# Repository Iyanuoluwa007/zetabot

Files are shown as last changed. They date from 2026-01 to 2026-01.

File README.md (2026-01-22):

<p align="center">
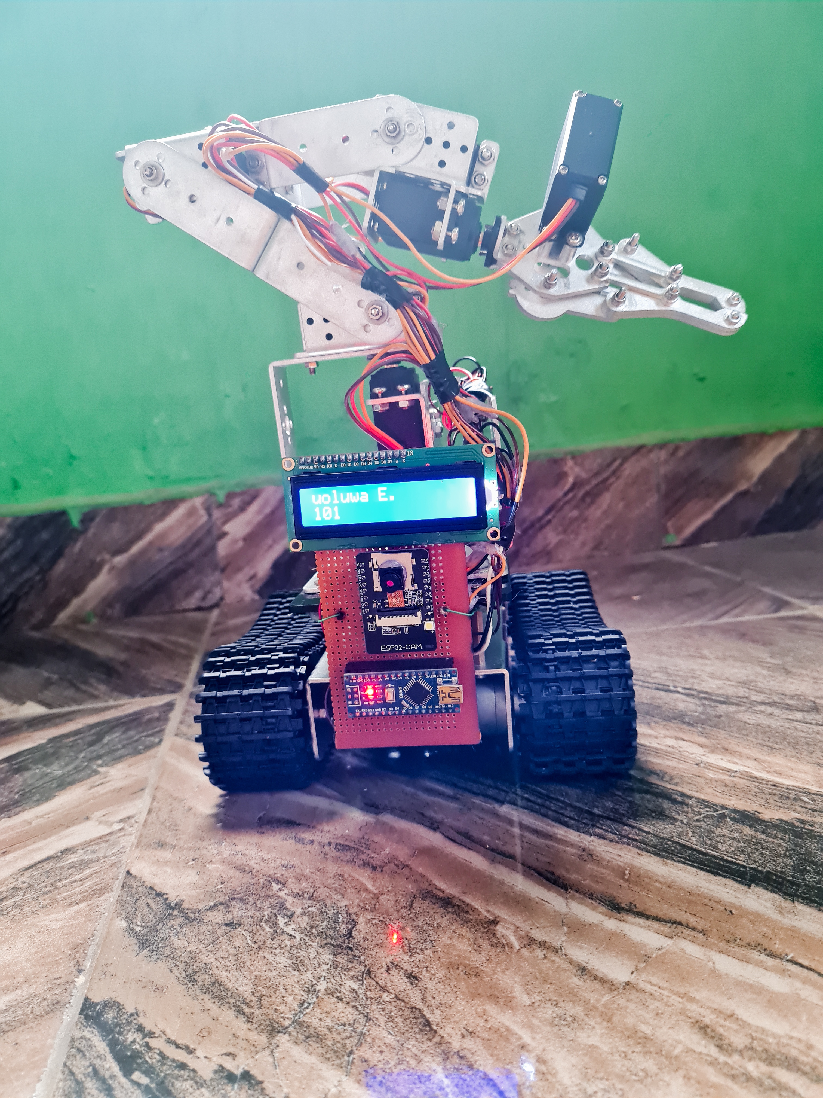
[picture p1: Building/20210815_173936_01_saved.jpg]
ZetaBot Robot
  
</p>

# 🤖 ZetaBot  
### Mobile Control Robotic Arm on Robotic Tank Wheel

> A low-cost, mobile robotic platform combining a robotic arm and tank-wheel locomotion, controlled via a custom Android app with live video streaming.

---

## 📌 Project Overview

**ZetaBot** is a research focused mobile robot designed for field applications such as agriculture, inspection, and robotics experimentation.  
It integrates a **robotic arm**, **tank wheel mobility**, **Bluetooth control**, and **Wi-Fi video streaming** using affordable, open-source hardware.

The system is controlled through a **custom Android application** built with Kodular, enabling real-time motion control and manipulation.

---

## 🧠 Key Features

✅ Mobile tank-wheel navigation  
✅ 6 - DOF robotic arm control  
✅ Android app control (Bluetooth)  
✅ Live video streaming over Wi-Fi  
✅ Low-cost, modular, and scalable design  
✅ LCD status feedback  
✅ Open-source software stack  

---

## ⚙️ System Architecture
**Control Flow:**

<p align="center">
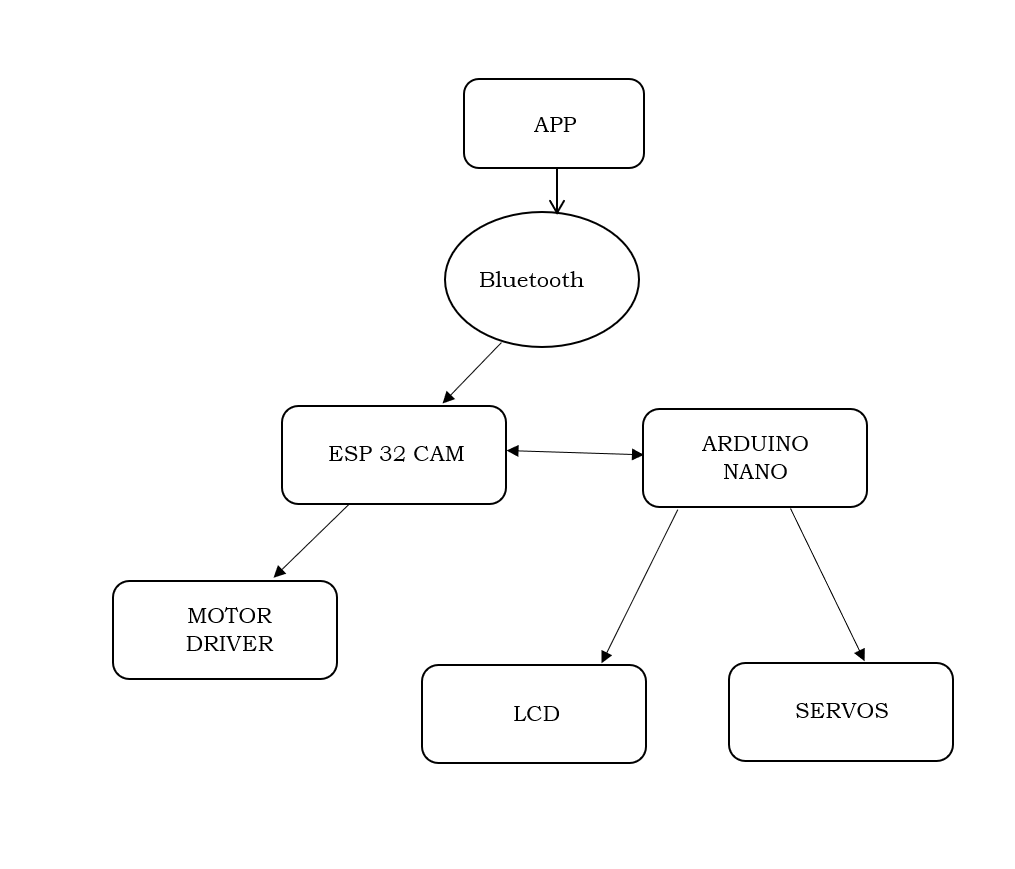
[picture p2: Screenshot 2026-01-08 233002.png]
ZetaBot System Architecture
  
</p>

- Android App → Bluetooth → ESP32-CAM  
- ESP32-CAM → Motor Driver (movement)  
- ESP32-CAM → Arduino Nano (arm & LCD)  
- ESP32-CAM → Wi-Fi → Live video stream  

---

## 🧩 Hardware Components

- ESP32-CAM (Wi-Fi + Bluetooth + camera)
- Arduino Nano
- L298N Motor Driver
- MG996R / MG995 Servo Motors
- 12V DC Geared Motors (Tank Wheels)
- 16×2 I2C LCD Display
- 18650 Lithium Batteries (3S & 2S)
- XL6019 DC - DC Boost Converter
- Solar Panel (5.5V, optional)
- Android Smartphone (Controller)

---

## 💻 Software & Tools

- **Arduino IDE** – Firmware development  
- **Kodular** – Android app builder  
- **ESP32 Camera Web Server** – Live video streaming  
- **C / C++** – Embedded programming  

---

## 📱 Mobile Application

The Android app is divided into two sections:

🔹 **Tank Control**
- Forward / Backward
- Left / Right
- Stop
- Headlight control

🔹 **Robotic Arm Control**
- Waist rotation  
- Shoulder movement  
- Elbow control  
- Grip open/close  
- Roll & pitch control  

---

## 🎥 Live Video Streaming

- ESP32-CAM streams live footage over Wi-Fi  
- Accessed via browser using ESP32 IP address  
- Useful for remote inspection and monitoring  

---

## 🧪 Results

✔ Stable movement and arm manipulation  
✔ Reliable Bluetooth communication  
✔ Clear live video stream over local Wi-Fi  
✔ Successful integration of all subsystems  

---

## 🚀 Applications

- Agricultural field research  
- Robotics education & prototyping  
- Remote inspection  
- Mechatronics research platform  
- Smart surveillance experiments  

---

## ⚠️ Limitations

- Bluetooth range limited compared to full internet control  
- Requires stable Wi-Fi for video streaming  
- Arm payload limited by servo torque  

---

## 🔮 Future Improvements

- Full internet based control (IoT)
- Autonomous navigation (SLAM)
- Object detection using computer vision
- Stronger servos & metal arm structure
- Cloud based monitoring dashboard

---

## 🎓 Academic Context

**Project Title:**  
*Design and Construction of a Mobile Control Robot Arm on a Robotic Wheel*

**Degree:**  
Bachelor of Engineering (B.Eng.) – Electrical & Information Engineering  

**Institution:**  
Landmark University, Nigeria  

**Year:**  
2022  

---

## 👤 Author

**Iyanuoluwa Enoch Oke**  
Robotics & AI Engineer  
📧 Email: [oke.iyanuoluwa12@gmail.com](mailto:oke.iyanuoluwa12@gmail.com)
🔗 LinkedIn: [Iyanuoluwa Enoch Oke](https://www.linkedin.com/in/iyanuoluwa-enoch-oke/)

---

## 📖 Citation & DOI

If you use this project in your research or work, please cite:

Oke, I. E. (2026). *ZetaBot: Mobile robotic platform with live video streaming and 6-DOF arm* (Version 1.0.1) [Software]. Zenodo.  
https://doi.org/10.5281/zenodo.18341042



---

⭐ *If you like this project, consider giving it a star!*  

---

## 🖼️ Project Gallery

<p align="center">
  
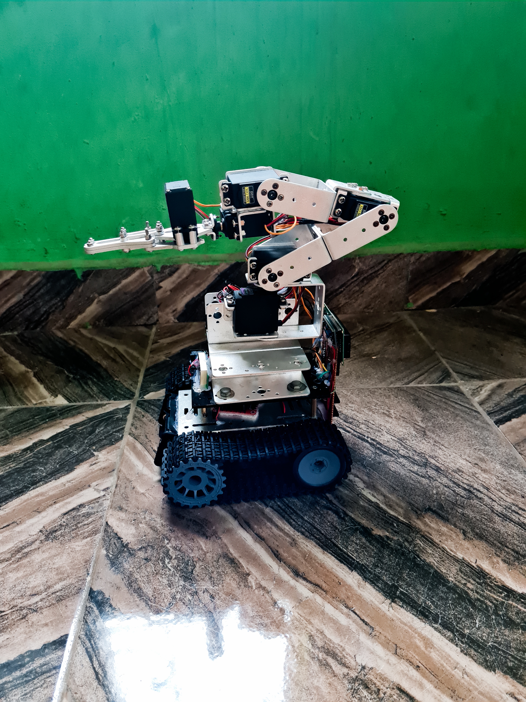
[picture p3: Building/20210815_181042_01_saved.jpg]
  
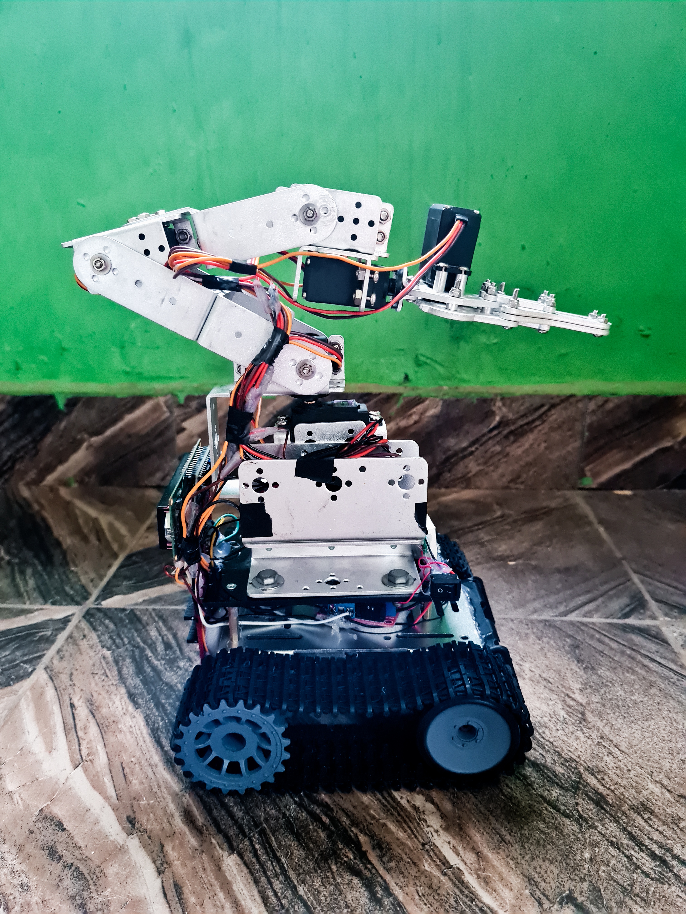
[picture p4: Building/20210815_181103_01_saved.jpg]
  
</p>

<p align="center">
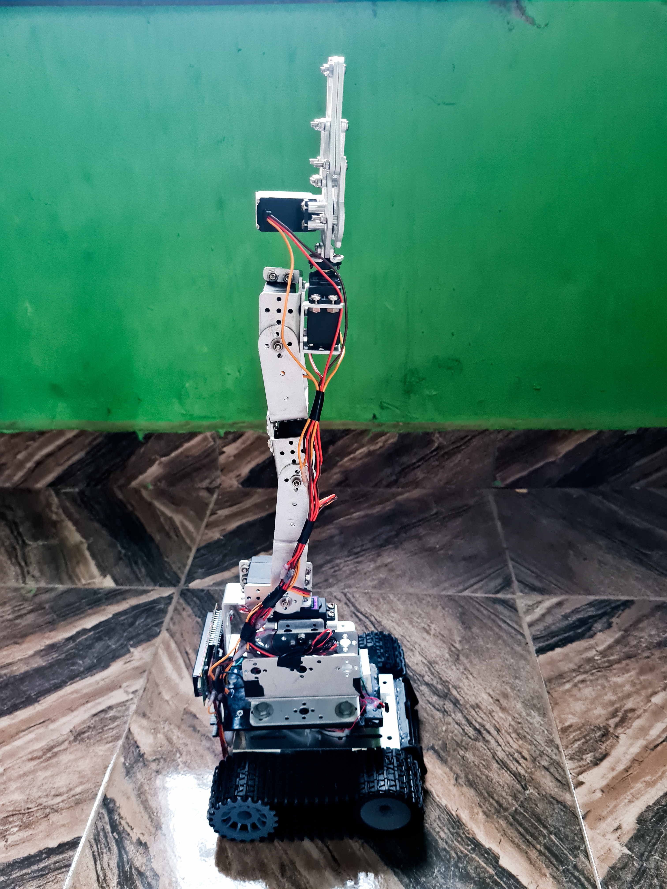
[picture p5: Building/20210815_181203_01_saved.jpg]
  
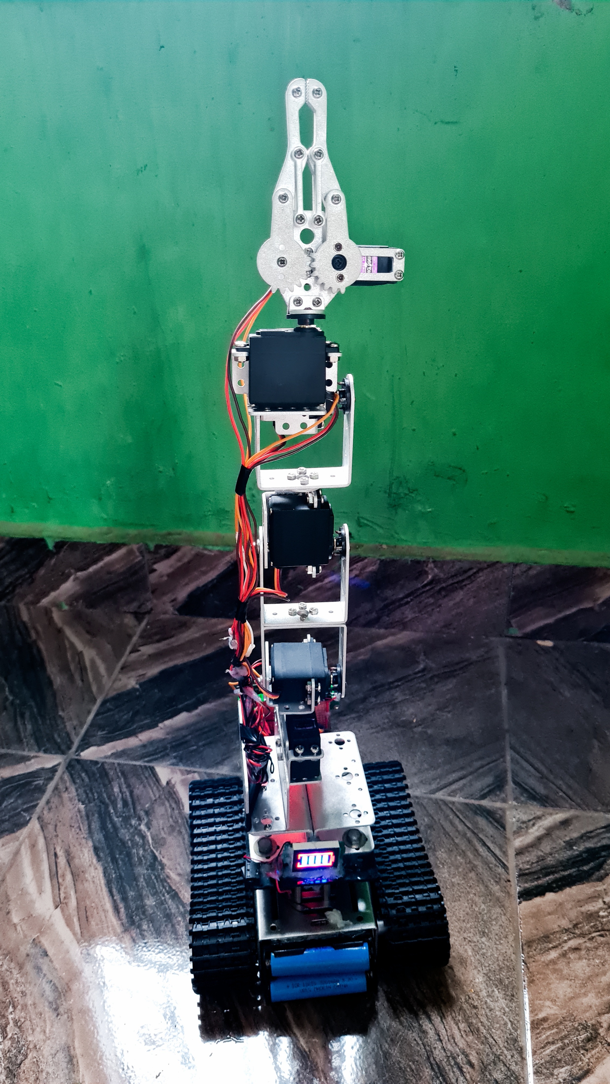
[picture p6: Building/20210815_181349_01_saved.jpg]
  
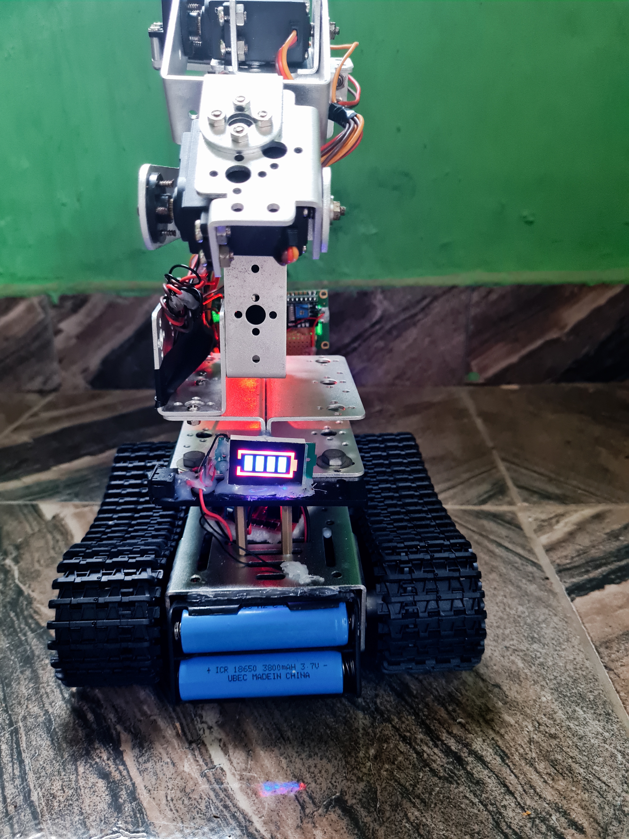
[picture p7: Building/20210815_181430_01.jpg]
  
</p>

### The app interface:
<p align="center">
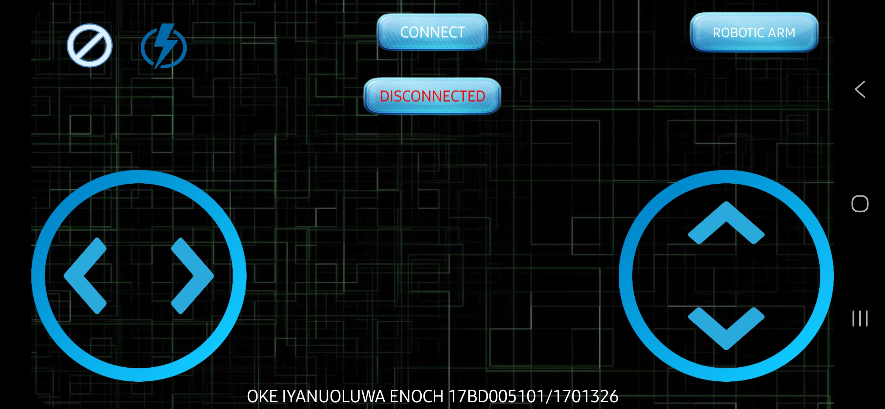
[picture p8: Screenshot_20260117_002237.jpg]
  
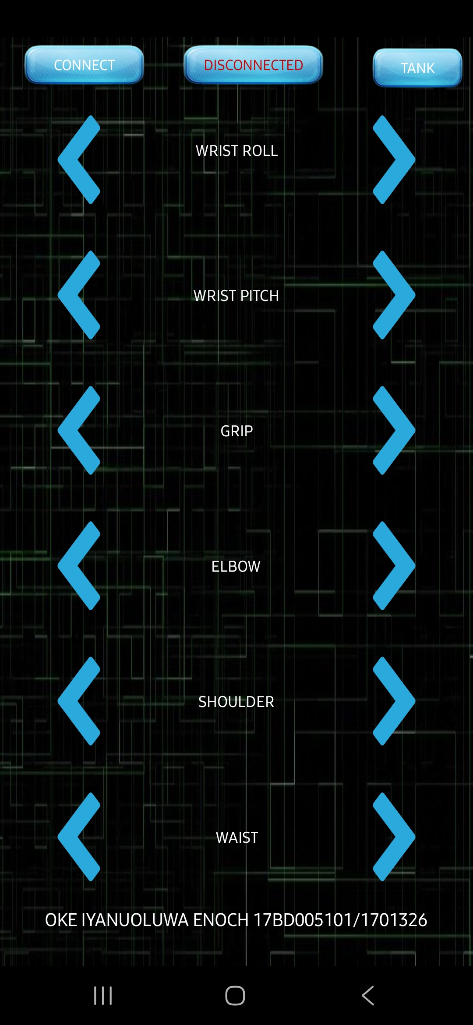
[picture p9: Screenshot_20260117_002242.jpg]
  
</p>

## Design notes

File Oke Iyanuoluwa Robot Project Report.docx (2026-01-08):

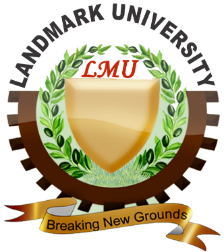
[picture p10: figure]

DESIGN AND CONSTRUCTION OF A MOBILE CONTROL ROBOT ARM ON A ROBOTIC WHEEL

BY

OKE IYANUOLUWA ENOCH

17BD005101/1701326

A PROJECT REPORT SUBMITTED TO

THE DEPARTMENT OF ELECTRICAL AND INFORMATION ENGINEERING

COLLEGE OF ENGINEERING

LANDMARK UNIVERSITY, OMU-ARAN, KWARA STATE, NIGERIA

IN PARTIAL FULFILLMENT OF THE REQUIREMENTS FOR THE AWARD OF BACHELOR OF ENGINEERING (B.ENG.) DEGREE IN ELECTRICAL AND INFORMATION ENGINEERING.

JULY 2022.

CERTIFICATION

The undersigned certifies that this project report, Titled ROBOTIC ARM ON ROBOTIC TANK WHEEL (ZETABOT) USING ESP 32 AND ARDUINO NANO was carried out by OKE IYANUOLUWA ENOCH, with Matriculation number 17BD005101 and meets the requirement of the Department of Electrical and Information Engineering (B.Eng.) degree in Electrical and Information Engineering.

__________________________ ___________________________

DR. P.K OLULOPE Date

(Supervisor)

_____________________________ _____________________________

DR. P.K OLULOPE Date

(Ag. Head of Department)

______________________________ _____________________________

(External Examiner) Date

DEDICATION

I dedicate this project work to the Almighty God, the source of my help and inspiration during this project, who has always been on my side throughout my academic journey at Landmark University. To my supervisor, Dr. P. K. Olulope without whose never-failing attitude to work, encouraging and scrutiny, this project would not have been as it is. I also dedicate this project to my family, the family of Mr Oke Babatunde who has been my source of everything throughout my academic career and also to my friends, and lecturers who were there for me and made an impact throughout this facet of my academic life.

ACKNOWLEDGEMENT

I would love to acknowledge the management of Landmark University for providing a conducive environment for learning and to carry out this project successfully.

I would also like to express my special thanks of gratitude to my supervisor Dr. P. K Olulope who gave me the golden opportunity to do this wonderful project on the Topic Robotic Arm on Robotic Tank Wheel Using Esp 32 And Arduino Nano, which also helped me in doing a lot of research and I came to know about so many new things. I am grateful.

Secondly, I would also like to thank my parents and friends, who helped me a lot in finalizing this project within the limited time frame.

SECTION | CONTENTS | PAGE
ii | CERTIFICATION | ii
iii | DEDICATION | iiI
iv | ACKNOWLEDGEMENT | iv
v | TABLE OF CONTENTS | v – vi
vii | TABLE OF FIGURES | vii
1 | CHAPTER 1: INTRODUCTION
1.1 | INTRODUCTION | 1
1.2 | BACKGROUND OF STUDY | 1
1.3 | AIM AND OBJECTIVES | 2
1.4 | SCOPE AND LIMITATIONS OF THE PROJECT | 2
1.5 | STATEMENT OF THE PROBLEM | 3
2 | CHAPTER 2: LITERATURE REVIEW
2.1 | HISTORY OF ROBOTICS | 4
2.2 | THE FIRST MODERN ROBOTS | 4
2.3 | MICROCONTROLLER | 5
2.3.1 | TERMINOLOGY | 5
2.3.2 | ESP 32 | 5
2.3.3 | ARDUINO NANO | 8
2.3.4 | POWER SUPPLY | 9
2.3.5 | SERIAL COMMUNICATION | 9
2.4 | MOTOR DRIVER | 9
2.5 | MOTOR | 12
2.6 | SERVO | 13
2.7 | 16 * 2 LCD SCREEN | 14
2.8 | ARDUINO IDE | 15
2.9 | KODULAR | 16
2.11 | 18650 15A 3S CHARGER MODULE | 17
2.12 | XL6019 DC TO DC BOOSTER MODULE | 17
2.13 | 5.5v 70ma SOLAR PANEL | 18
3 | CHAPTER 3: DESIGN AND METHODOLOGY
3.1 | RESEARCH METHODOLOGY | 19
3.2 | TOOLS | 20
3.2.1 | HARDWARE | 20
3.2.2 | SOFTWARE | 20
3.3 | SYSTEM DESIGN | 21
3.4 | CIRCUIT DESIGN | 22
3.5 | METHODOLOGY | 23
3.5.1 | SETTING UP THE ESP 32 CAM AND ARDUINO NANO ON ARDUINO IDE | 23
3.5.2 | BUILDING THE APP ON KODULAR | 23
3.5.4 | CONNECTING I2C LCD TO THE ARDUINO NANO | 24
3.5.5 | CONNECTING SERVO TO THE ARDUINO NANO | 24
3.5.6 | CONNECTING THE MOTOR CONNECTED TO MOTOR DRIVER TO ESP 32 CAM | 25
3.5.7 | PROGRAM CODE | 26
4 | CHAPTER 4
4.1 | RESULTS AND DISCUSSION | 43
5 | CHAPTER 5
5.1 | RECOMMENDATION | 44
5.2 | CONCLUSION | 44
| REFERENCES | 45

Fig 2.3.2 | LAYOUT OF ESP 32 CAM | 8
Fig 2.3.3 | LAYOUT OF ARDUINO NANO | 8
Fig 2.4.1 | SCHEMATIC DIAGRAM FOR MOTOR DRIVE MODULE | 11
Fig 2.4.2 | LAYOUT OF L298N MODULE | 11
Fig 2.5 | DIAGRAM OF 12V330 GEARED MOTOR | 13
Fig 2.6.1 | SCHEMATIC DIAGRAM FOR MG996R SERVO MOTOR | 13
Fig 2.6.2 | LAYOUT OF MG996R SERVO MOTOR | 14
Fig 2.7 | LAYOUT OF 16 X 2 LCD | 14
Fig 2.8 | ARDUINO IDE | 15
Fig 2.9 | LAYOUT OF KODULAR | 16
Fig 2.10 | LAYOUT OF 18650 15A 3S CHARGER MODULE | 17
Fig 2.11 | LAYOUT OF XL6019 DC TO DC BOOSTER MODULE | 18
Fig 2.12 | LAYOUT OF 5.5V 70MA SOLAR PANEL | 18
Fig 3.1 | FLOW CHART OF RESEARCH METHODS | 19
Fig 3.3.1 | BLOCK DIAGRAM | 21
Fig 3.3.2 | PICTORIAL CIRCUIT DIAGRAM | 22
Fig 3.4 | CIRCUIT DIAGRAM | 22
Fig 3.5.4 | CONNECTING THE I2C LCD TO THE ARDUINO NANO | 24
Fig 3.5.5 | CONNECTING SERVO TO THE ARDUINO NANO | 25
Fig 3.5.6 | PICTORIAL CIRCUIT DIAGRAM OF CONNECTING THE MOTOR CONNECTED TO MOTOR DRIVER TO ESP 32 CAM | 26
Fig 4.1 | FINAL CONSTRUCTED PROJECT RESULT | 43

TABLE OF FIGURES

CHAPTER 1

1.1 INTRODUCTION

It is true that in recent years, the power, functionality, and ubiquity of computers and the Internet have outpaced earlier projections for the rate of technological innovation and utility in everyday life. Experts anticipate that the world will soon be flooded with sophisticated computer chips, which will progressively find their way into our products, houses, clothes, and even our bodies.

A nearly similar goal, on the other hand, has remained elusive. Unlike the widely unanticipated main streaming of computers, the robotics team failed to live up to the 1950s predictions. Experts were astounded by the possibilities at this point. The computer's seemingly magical computation believes that precisely the proper software is written down. Computers have the potential to become the artificial brains of advanced autonomous robots. They believe that such robots will mop floors, mow lawns, and generally eradicate chores from our life in a decade or two.

That did not appear to be the case. Industrial robots have had a significant impact on the automobile sector, as well as other industries. However, this level of automation falls far short of what many scientists and engineers had hoped for in terms of versatility, portability, and automation. Thousands of researchers have become frustrated in their pursuit of these robots, and hundreds of firms have gone bankrupt. It's not that the mechanical "body" is unreachable; industrial robots demonstrate that articulated arms and other mobile systems appropriate for manual tasks already exist. Instead, the computerized pairing brain has not yet advanced to the level of sophistication required to construct a human-like robot.

1.2 BACKGROUND OF STUDY

In a variety of fields, robots are gaining traction. Almost every day, we read in the press about robots in nursing homes giving the old company or cars that can park or even drive themselves without human supervision. It appears that the world is becoming increasingly automated when we call a corporation and are connected to a computer. And the robots are getting smarter; scientists are working on making more friendly robots that can read facial expressions and have conversations.

The progression appears to go from limited industrial robots to increasingly autonomous machines and systems, with singularity machines outsmarting humans in science fiction films like Terminator or I-Robot at the extreme, more speculative end of the spectrum.

In this thesis, the word "autonomous system" is used to refer to several phrases such as "robot," "artificial agent," and "unmanned aerial vehicle." The autonomy, not necessarily the embodiment commonly associated with robots, is the relevant feature for the philosophical concerns in the thesis. It's just as important to have an autonomous system integrated in something that isn't a robot. However, as it is in the literature, the term robot is most usually used.

Although roboticists do not appear to agree on how to interpret the term robot, autonomy or independence appears to be a common denominator. A computer attached to a printer, for example, would be a robot if it were defined as "a computer with sensors and actuators that allow it to interact with the external world." Something more, some amount of "thinking" or "doing," is required to distinguish it from automata such as thermostats or computers attached to printers.

1.3 AIM AND OBJECTIVES

1.3.1 AIM:

To develop a low-cost research robot used in any area of field.

1.3.2 OBJECTIVES:

Objective of this project are as follows:

i. To design an inexpensive system that is user-friendly and easy to use.
ii. To construct a mobile app control robot for research purpose.
iii. To develop an internet base control system that enables transfer and receiving data through the internet.
iv. To interface the system with an internet android application enabling cloud data communication.

1.4 SCOPE AND LIMITATIONS OF THE PROJECT

The project scope, which is in line with its aim to use an affordable agrotechnology robot, targets for field research that is controlled via a mobile app. Esp 32 Cam and Arduino Nano are the main microcontrollers used for the system as communication to a cloud store through the internet between the cloud store and the mobile app.

The project will not be limited to just field research purposes only. A Kodular Mobile Application, Bluetooth serves as the intermediate between the user sending instructions through Bluetooth connection.

1.5 STATEMENT OF THE PROBLEM

Despite robot researchers' efforts and research, the goal of emulating human intelligence and appearance has yet to be reached. The majority of robots are not adaptable, and they do not recognize objects effectively. Prioritizing the inefficiencies connected with robotics technology is critical for its successful and proper operation. Though widespread usage of robotics technology will eliminate many human jobs, it will result in increased unemployment in the society. Because the use of robots to do diverse tasks will result in the loss of human jobs, the implementation should be done systematically. Robotic advancements will reduce the number of high-end precision tasks and will benefit a variety of industries, including agriculture, military, and health care. As a result, robots will be used as workplace assistants with a degree of balance between genuine requirements and greed. Many jobs that are beyond human capability can be accomplished with the aid of robotics, which will be quite beneficial in its functioning. The growth of robot technology will be incredible, and robots can now be found in almost every field, from transportation to health, recreation to industry.

CHAPTER 2

LITERATURE REVIEW

2.1 History of Robots

One of the first examples of a mechanical device designed to do a particular physical task on a regular basis may be found in Egyptian water clocks from around 3000 B.C. These clocks used human figures to strike the hour bells. The pulley and screw were constructed by Archytus of Taremtum, who also invented a flying wooden pigeon in 400 B.C. Hydraulically powered statues that could speak, gesture, and prophesy were common in Hellenistic Egypt during the second century B.C.

A doll that resembles a human was made in the first century AD by Petronius Arbiter. Giovanni Torriani created a wooden robot that could deliver the Emperor's daily bread in 1557. Before the twentieth century, the number of inventive but unusable automata (i.e., robots) reached its height in the 1700s. The nineteenth century saw the development of numerous new robotic creations, such as Thomas Edison's talking doll and a steam-powered robot created by Canadians. The modern robot was made possible by scientific developments in the field of robotics made in the 20th century, despite the fact that previous historical advances may have planted the seeds of inspiration for it. The modern robot may have been inspired by these historical findings, but scientific advancement in the field of robotics in the 20th century far exceeds earlier successes.

2.2 The First Modern Robots

Early in the 1950s, a man from Louisville, Kentucky named George C. Devol created the first robots as we know them today. The "Unimate," or "Universal Automation," reprogrammable manipulator was created by him, and it was granted a patent. For the following ten years, he made failed attempts to market his products in the sector. Businessman and engineer Joseph Engleberger purchased Devol's robot patent in the late 1960s and turned it into an industrial robot. He then founded Unimation to produce and sell the robots. Because of his contributions, Engleberger is known in the industry as "the Father of Robotics." New robot development has advanced significantly in academia as well. In 1958, Charles Rosen oversaw a research group at Stanford Research Institute that created "Shakey," a considerably more advanced robot than the Unimate that had been created initially for specialized industrial applications. Shakey was able to walk around the space, see the action through his television "eyes," travel across uncharted territory, and to some extent react to his environment. He was given the name because of his clumsy and clattering actions.

2.3 MICROCONTROLLER

2.3.1 TERMINOLOGY

A microcontroller is a single-chip microcomputer made with VLSI technology. Microcontrollers are frequently referred to as embedded controllers. Microcontrollers with varied word lengths, such as 4bit, 8bit, 64bit, and 128bit microcontrollers, are now available on the market. Microcontrollers are compact microcomputers used to control the functions of embedded systems in office equipment, robotics, home appliances, automobiles, and other devices. Memory, peripherals, and, most crucially, a CPU are all included in a microcontroller.

Microcontrollers are primarily used in gadgets that require the user to exercise some level of control.

2.3.2 ESP 32 CAM

This project also made use of Esp 32 Cam. With the ESP32-S chip, the ESP32-CAM is a very compact camera module. The camera on the module is an OV2640. Additional GPIOs are available for connecting devices. The controller is built on a 32-bit CPU that operates at a maximum frequency of 240MHz. It contains an external 4M PSRAM in addition to its internal 520 KB SRAM. It has a SoC module that combines 802.11b/g/n Wi-Fi and Bluetooth/BLE. It supports embedded Lwip, FreeRTOS, and image Wifi upload. There is a PSRAM Chip with an onboard voltage regulator IC. The board is breadboard friendly and contains a single reset button. On the board, there is an LED that can be utilized as a signal.

This module comes with an antenna built in, and if an extra antenna with more power and range is required, it may be connected to the IPEX connector. You must attach a jumper or a zero-ohm resistor on the PCB next to the antenna in order to utilize it.

ESP32-CAM Specifications

Since the ESP32-CAM is based on the ESP32-S module, it has similar features. It has these characteristics:

i. 802.11b/g/n Wi-Fi
ii. Bluetooth 4.2 with BLE
iii. UART, SPI, I2C and PWM interfaces
iv. Clock speed up to 160 MHz
v. Computing power up to 600 DMIPS
vi. 520 KB SRAM plus 4 MB PSRAM
vii. Supports Wifi Image Upload
viii. Multiple Sleep modes
ix. Firmware Over the Air (FOTA) upgrades are possible
x. 9 GPIO ports
xi. Built-in Flash LED

OV2460 Camera

The Camera Module is the most crucial component of the ESP32 CAM. The OV2640 Camera Module, which includes a 24 Pin Camera Holder, is the available Camera Module. It features a camera resolution that is the highest, at 1600 1200.

There is a connecting strip with gold plating. The camera and ESP32 are connected using this connector.

SD Card Support

An SD Card Holder that can accommodate cards up to 16GB is located on the back. When creating projects that rely on photographs, the SD card is utilized to store the images. Simply placing the SD Card into the SD Card Adapter establishes the connection.

Camera Specifications

On the back, there is an SD Card Holder that can hold cards up to 16GB. The SD card is used to store the images when developing projects that rely on photos. The connection is made simply by inserting the SD Card into the SD Card Adapter

i. 2 Megapixel sensor
ii. Array size UXGA 1622×1200
iii. Output formats include YUV422, YUV420, RGB565, RGB555 and 8-bit compressed data
iv. Image transfer rate of 15 to 60 fps

ESP32 CAM GPIO Pins

Numerous GPIO pins, including UART, SPI, I2C, PWM, ADC, and DAC, are supported. This module provides both a 5V pin and a 3.3V VCC pin. Additionally, there are several GND Pins.

The following pins are internally connected to the microSD card reader:
GPIO 14: CLK
GPIO 15: CMD
GPIO 2: Data 0
GPIO 4: Data 1 (also connected to the on-board LED)
GPIO 12: Data 2
GPIO 13: Data 3

ESP32-CAM FTDI Connection

For the purpose of programming the board, a USB-to-TTL Converter Module or an FTDI Module must be used; there are numerous FTDI Module options based on the CP2102 or CP2104 chip, among others.

Make the connection between the FTDI module and the ESP32 CAM module as shown below to get started with the module.

Connect the ESP32's 5V and GND pins to the FTDI module's 5V and GND pins. Rx and Tx should be similarly connected to UOT and UOR Pin. The IO0 and GND Pins must be connected via a short circuit, which is the most crucial step. In order to program the device, do this. After programming is complete, the IO0 and GND must be removed. The Esp 32 Cam can be programmed using the Arduino IDE software and is compatible with LUA, Java, C, and C++. The design of Esp 32 Cam is seen in the figure.

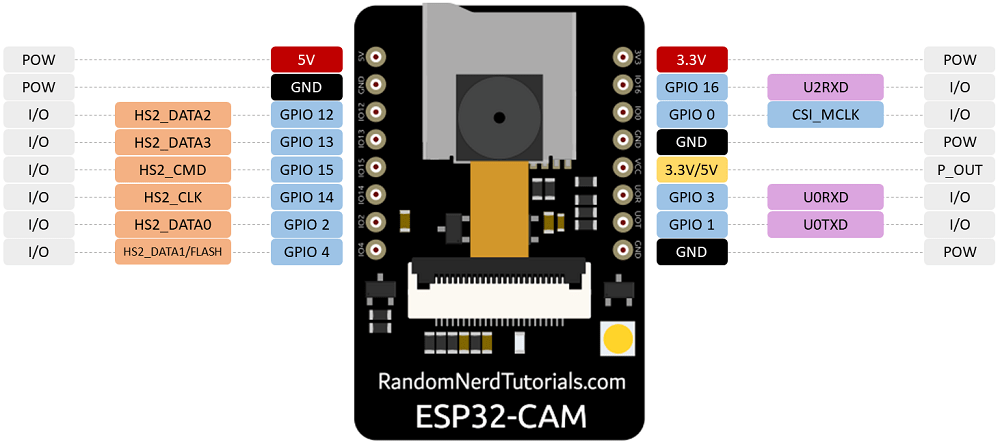
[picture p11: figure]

Fig 2.3.2: Layout of Esp 32 Cam

2.3.3 ARDUINO NANO

For this project, an Arduino Nano board was also utilized. It is an ATmega328-based, surface-mount embedded version of Arduino that is compact, complete, and compatible with breadboards. Electrically speaking, it is identical to the Arduino Diecimila save for having more analog input pins and a built-in +5V AREF jumper. The Nano 3.0 connects to a computer using a Mini-B USB cable and can be powered by a 5V regulated external power supply, a 6-20V unregulated external power supply, or the Mini-B USB connection (pin 30). (pin 27). The greatest voltage source is automatically chosen as the power supply. The Nano features more breadboard space for users thanks to its smaller size than either the Arduino Uno or Micro, which both have breadboard functionality. Additionally, it has a pin arrangement that complements the Mini or the Basic Stamp (TX, RX, ATN, GND on one side, power, and ground on the other).

The Arduino Nano may be programmed using the Arduino IDE software, and it supports the programming languages LUA, Java, C, and C++. The Arduino Nano's layout is seen in the figure.

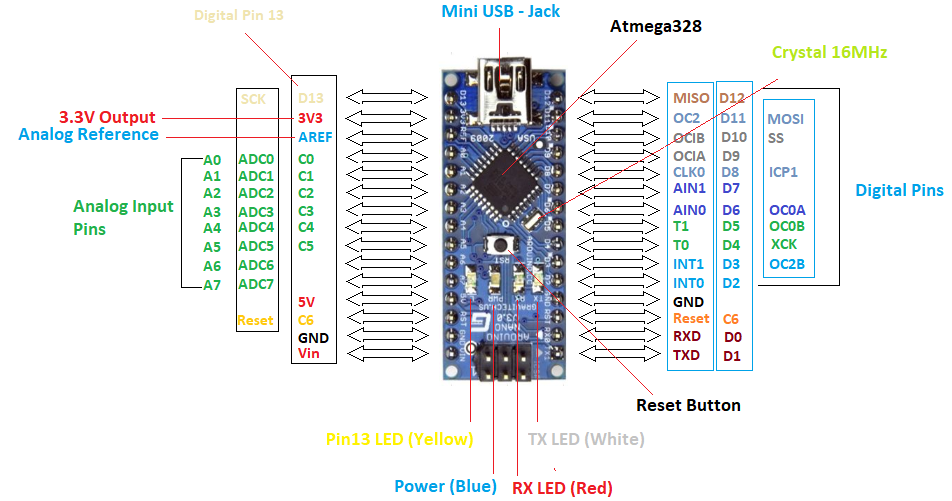
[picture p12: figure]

Fig 2.3.3: Layout of Arduino Nano

2.3.4 POWER SUPPLY

Esp 32 Cam Power Supply

The Esp 32 Cam can be power by two methods which are through the onboard VIN pin through which a regulated 5v voltage source is connected to and also through FTDI Module to a computer system. The Esp 32 cam can be activated with voltages ranging from 3.3v to 5v. The Esp 32 Cam has an AMS1117 voltage regulator that creates the required voltage for the Esp. The AMS1117 has an absolute maximum input voltage of 15V. It has a dropout voltage of 1.1v -1.3v. The onboard 5v and 3.3v pin can supply power to connected devices.

Arduino Nano Power Supply

The Arduino Nano can be power by two methods which is through the on-board Mini-B USB connector to a computer system and the onboard VIN pin through which a regulated 5v. The Arduino Nano has an LM1117IMPX-5.0 voltage regulator that supplies 5v to the Arduino Nano. The LM1117IMPX-5.0 has an absolute maximum input of 20v. The LM1117IMPX-5.0 supports input voltages between 7V and 12V with a maximum current of 900mA. The onboard 5v and 3.3v pin can supply power to connected devices.

2.3.5 SERIAL COMMUNICATION

Serial communication is used for communication between the Arduino boards and a computer or other devices. All Arduino boards have at least one serial port (also known as a UART or USART). It communicates on digital pins 0 (RX) and 1 (TX) as well as with the computer via USB.

2.4 MOTOR DRIVER

An integrated circuit chip called a motor driver IC is used to control motors in embedded and autonomous robotic systems. The L293D and ULN2003 are the most often utilized motor driver ICs in small robots and remote-controlled autos. Undoubtedly, a motor driver is something that makes a motor move in response to directions or inputs (high and low). It uses the low voltage provided by the controller or processor to drive a genuine motor, which needs a high input voltage. The motor driver IC controls the direction of the motor in accordance with the directives or instructions it gets from the controller.

The L298N Motor Driver Module

A monolithic circuit is built into the 15-lead Multiwatt and PowerSO20 packaging known as the L298N. It is a twin full-bridge high-voltage, high-current driver capable of driving inductive loads such as relays, solenoids, DC motors, and stepping motors. Two independent of input signal enable inputs can be used to enable or disable the device. An external sensing resistor can be connected to the corresponding external terminal once the bottom transistor emitters of each bridge have been connected together. An additional supply input is included to enable the logic to function at a lower voltage.

Specification

i. Driver: L298N
ii. Driver power supply: +5V~+46V
iii. Driver Io: 2A
iv. Logic power output Vcc: +5~+7V (internal supply +5V)
v. Logic current: 0~36mA
vi. Controlling level: Low -0.3V~1.5V, high: 2.3V~Vss
vii. Enable signal level: Low -0.3V~1.5V, high: 2.3V~Vss
viii. Max power: 25W (Temperature 75 Celsius)
ix. Working temperature: -25C~+130C
x. Dimension: 60mm*54mm
xi. Driver weight: ~48g
xii. Other extensions: current probe, controlling direction indicator, pull-up resistor switch, logic part power supply.

Hardware Diagram

i. CSA: The current test pin for motor A, this pin can be wired to a resistor for current testing or tied to a jumper to disable it.
ii. CSB: The current test pin for motor B, this pin can be wired to a resistor for current testing or tied to a jumper to disable it.
iii. VMS: VMS is the 5V-35V power source for the motor. VMS is positive, GND is negative.
iv. 5V: Power input for the logic circuit on the board.
v. 5V-EN: 5V source jumper. When the jumper is put on, The 78M05 supplies the 5V power for the logic circuit on the board from the VMS port (7V < VMS < 18V). The power of the logic circuit of the board is supplied by the 5V port when this jumper is put off.
vi. U1/2/3/4: Pull up resistor for IN1/2/3/4. Putting on the jumper enable the pull-up resistor for the microcontroller, putting off it disable it.
vii. EA/EB: EA/EB is to enable pin for the two motors A/B, the motor speed also can be controlled by the PWM of this pin.
viii. IN1/2/3/4: IN1/2/3/4 is the pin for the motor control. Motor B is the same as Motor A.

Its schematic diagram and Layout is as shown in figure (a) and (b):

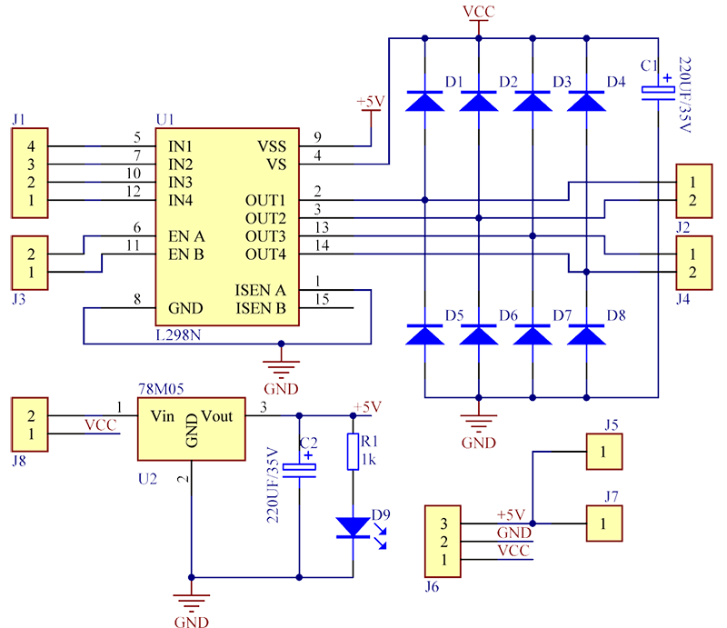
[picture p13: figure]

(a) Fig 2.4.1: Schematic diagram for motor drive module

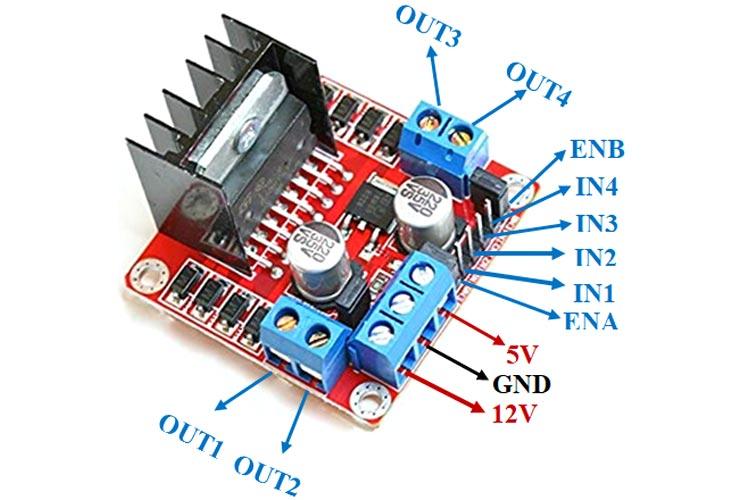
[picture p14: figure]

(b) Fig 2.4.2: Layout of L298N Module

2.5 MOTOR

A DC motor is any of a class of rotary electrical motors (https://en.wikipedia.org/wiki/Electrical_motor) that converts direct electrical current energy into mechanical energy. DC motor work on the current and voltage needed for the capabilities of microcontroller but DC moto is necessary to use some external device of electronic to drive the and control the motor, and it required individual power supply. There are many ways to drive the DC motor from the output of the device. However, transistors also use full to drive the DC motor and the other way to control the direction of the motor is L298N drive it is an integrated circuit.

How DC motor work

Stator, rotor, and armature are the three primary components of a DC motor. The revolving component known as the armature simple coil and a magnetic field are both present in the stator, which is permanently managed. Here, the armature is connected to the DC power source, and a two-piece ring that is attached within the motor shaft is known as the "commutator ring." A magnetic field was created by applying DC to the commutator, where flow travels through the coil.

Specification

i. Model: 112V330 to DC gear motor
ii. Rated Voltage: DC12V
iii. Original Speed: 1200rpm
iv. No-load Speed: 330rpm/0.24A
v. Maximum Efficiency Point: Load 4kg.cm/235rpm/2.5W/0.58A
vi. Maximum Power Point: Load 7kg.cm/215rpm/3.1W/0.65A
vii. Maximum locked rotor force: 13kg.cm
viii. Blocking Current: 4.8A
ix. Shaft Extension Size: 14.5mm
x. Motor Shaft Diameter: 4mm D3.5

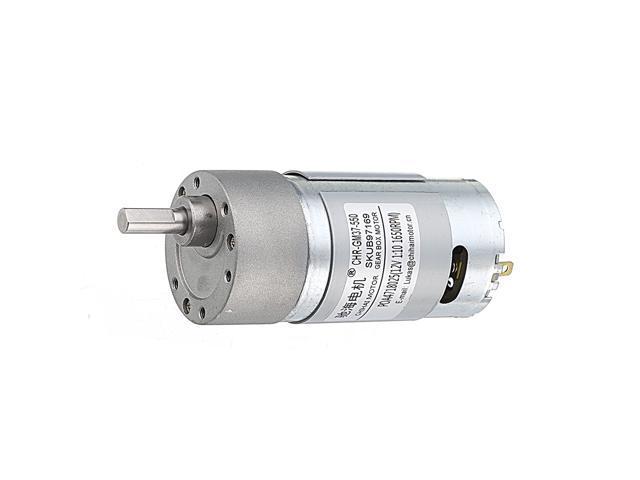
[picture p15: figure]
Engineering drawing Description generated with very high confidence

Fig 2.5: Diagram of 12v330 Geared Motor

2.6 SERVO

A servo motor is a rotary actuator or motor that enables exact angular position, acceleration, and velocity control. It possesses characteristics that a standard motor lacks. Standard servos are used to maintain a specific angle and use closed-loop feedback control. They are not intended for a full rotation. Servos are utilized in applications that require a lot of torque and precise rotation within a certain range of angles. The MG996R Servo Motor is a servo motor that uses PWM control signals to function. Based on the width of the pulse fed in by a signal input, the servo maintains a specific angle (position).

Specifications

i. Weight: 61 g
ii. Dimension: 54 x 38 x 20 mm approx.
iii. Gear Type: All Metal Gears
iv. Stall torque:12kg/cm(6V)
v. Power Supply: Through External Adapter
vi. Operation Voltage: 4.8 - 7.2 V
vii. Temperature range: 0'C to 55‘C
viii. Operating Speed: 0.17sec / 60 degrees (4.8V no load)
ix. Operating Speed: 0.13sec / 60 degrees (6.0V no load)
x. Pin configuration: Yellow / Light Orange / White (Signal), Red / Dark Orange (+5V), Brown/Black (Ground)

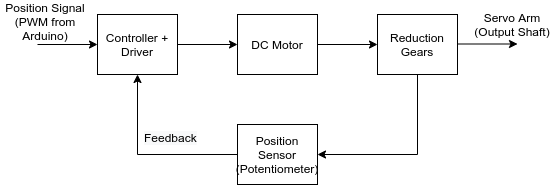
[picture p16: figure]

(a) Fig 2.6.1: Schematic diagram for MG996R Servo Motor

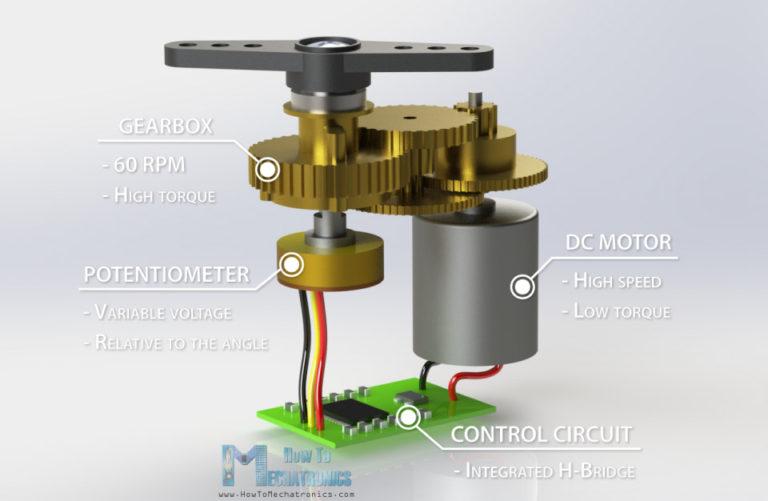
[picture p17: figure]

(b) Fig 2.6.2: Layout of MG996R Servo Motor

2.7 16 x 2 LCD SCREEN

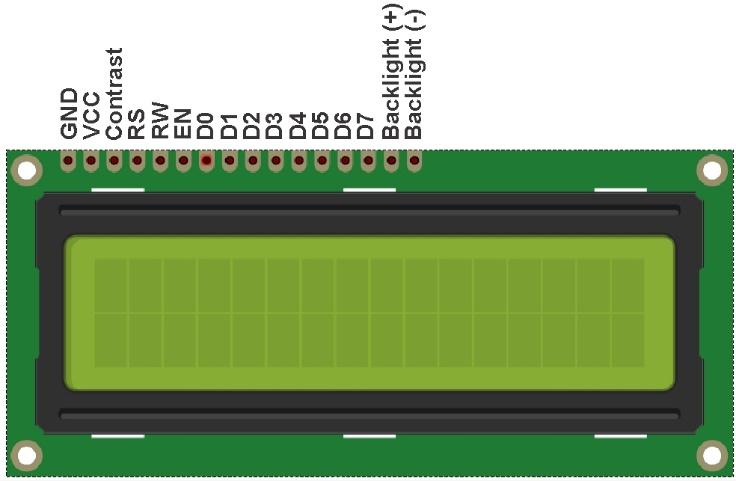
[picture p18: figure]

Liquid Crystal Display is an electronic module for displaying letters, numbers and characters. A 16 x 2 LCD means the screen can display 16 characters in two (2) lines. The LCD is used to display messages sent from Arduino Nano.

Fig 2.7: Layout of 16 x 2 LCD

2.8 ARDUINO IDE

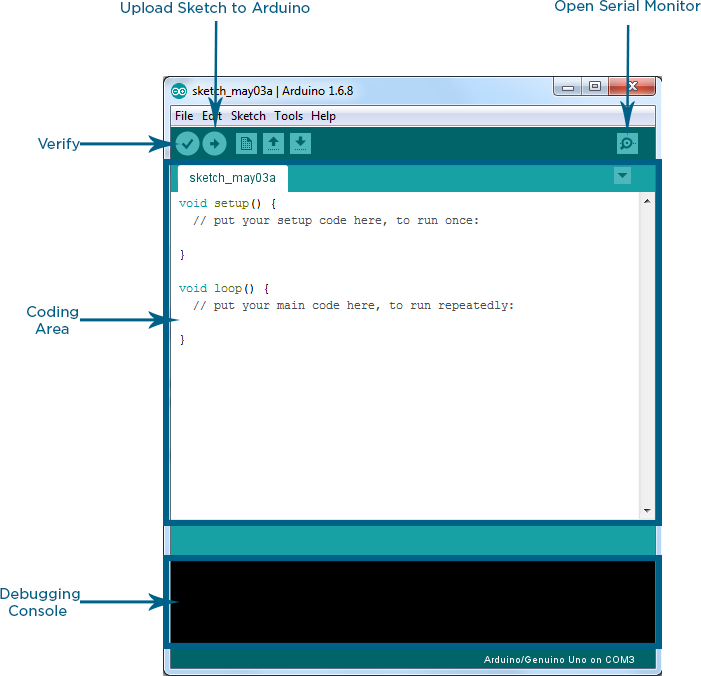
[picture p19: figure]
A picture containing graphical user interface Description generated with very high confidence

The Arduino IDE (Integrated Development Environment) is software that is used to write and upload codes to the Esp 32 Cam and Arduino Nano, after which it must have been installed on a computer system that may have a Linux, Windows or Mac OS X operating system. This software makes use of gcc, G++ compiler and accepts programs in C and C++. Appropriate settings must be done before coding on the software.

Fig 2.8: Arduino IDE

2.9 KODULAR

Kodular is an online suite that largely consists of an online web application that allows users to create apps without having to know how to code. Kodular Creator is an MIT App Inventor distribution, which means it's based on the App Inventor open source project, though it's a lot better. Kodular Creator, on the other hand, is not an open-source project, and the source code is hosted privately on GitHub, however, there are additional repositories related to the Suite. The most visible difference between this App Inventor package and the App Inventor open source project is that it has more components, more granular control over the app, and capabilities not found in the open-source version. The package also includes an online app store to compete with the Google Play Store, as well as an extensions IDE for advanced users to create additional Kodular Creator components. Kodular Account, a mechanism for controlling all of these services from a single location, is available to provide control over all of them.

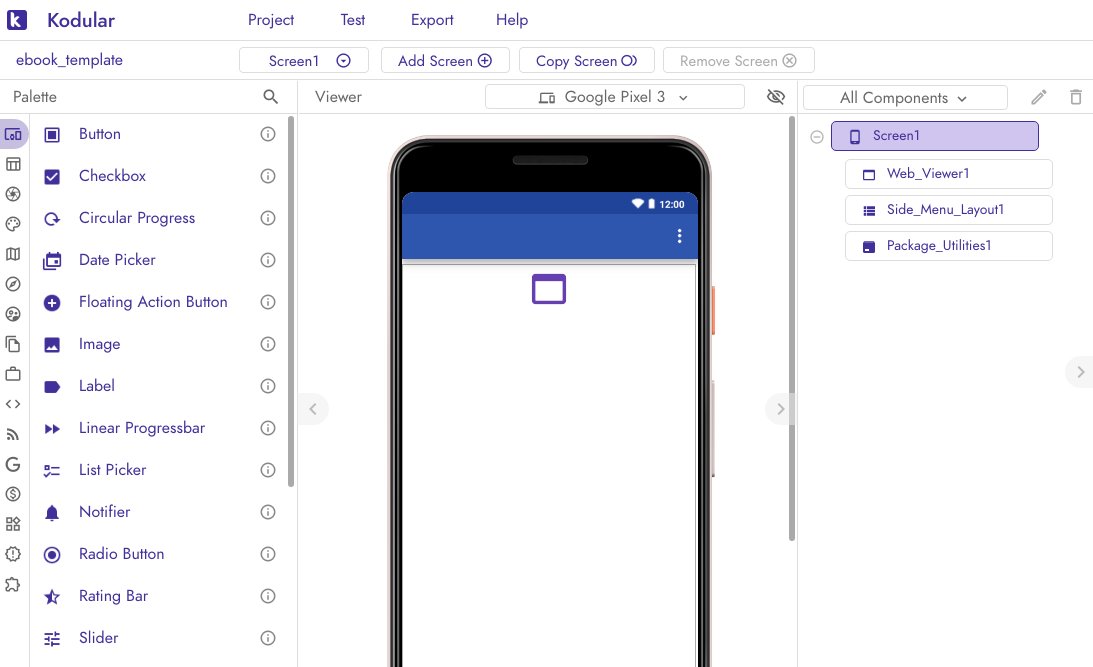
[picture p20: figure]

Fig 2.9 Layout of Kodular

2.10 18650 15A 3S CHARGER MODULE

This module is made for charging rechargeable lithium batteries using the constant-current/constant-voltage (CC/CV) charging method. In addition to safely charging a lithium battery the module also provides necessary protection required by lithium batteries.

The module specification

Model : HX-3S-FL25A-A

Charging voltage range: 12V

Over-discharge recovery voltage: 2.5v±0.05v,

Over-Discharge-Delay-Time: 144ms

Maximum Working Current: 10A

Maximum Peak current: 20A

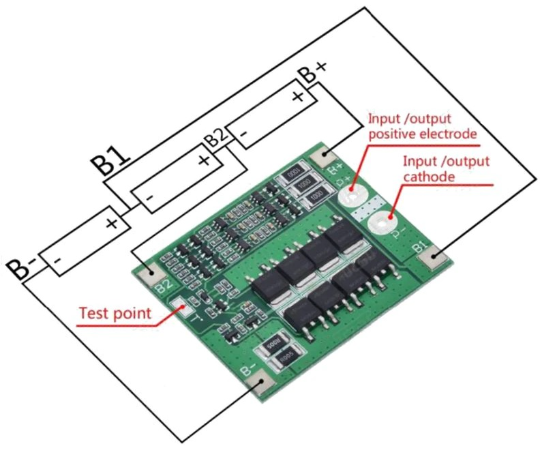
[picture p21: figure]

Fig 2.10: Layout Of 18650 15A 3s Charger Module

2.11 XL6019 DC TO DC BOOSTER MODULE

XL6019 DC-DC boost power supply module adjustable output regulator performance ultra LM2577 Model Specifications: XL6019 boost module Module Properties: non-isolated step-up Rectification: Non-Synchronous Rectification Input range: Limits: 3-40V, recommended values: 3V-35V Output Range: Limits: 5-45V, recommended values: 5V-40V (via rotary potentiometer) Input Current: Limits: 0-5A, recommended values: 0-3A Conversion efficiency: up to 94% Open frequency: 220KHz, the second generation of switching power supply technology Output ripple: less than 100mV Load regulation: &plusmn; 0.5% Voltage regulation: & plusmn; 0.5% Working temperature: Limits: -40 to +150 degrees Celsius, the recommended values: -20 to +85 degrees Celsius Reverse polarity protection: protection against reverse input 40V Size: 50MM 28MM 13MM With back protection, import TDK inductor, with a connecting column, the output 5V/12V/24V can be adjusted, performance beyond LM2577. Using conventional topology BOOST as a constant voltage output, the internal integration of MOSFET, peripheral devices, low system cost, built-in over temperature protection, over current protection of the full set of reliability protection circuit, high reliability. 1, the use of conventional topology BOOST complete set of constant voltage output, the internal integration of MOSFET, peripheral devices less, the system cost is low; 2, wide voltage range input, the input voltage up to 35V; 3, the output voltage can be adjusted, the highest can support 40V; 4, built-in over temperature protection, over current protection of the full set of reliability protection circuit, high reliability; 5, system conversion efficiency can reach more than 90%, easy to heat design; 6, TO263-5L standard package, suitable for 30W within the boost application.

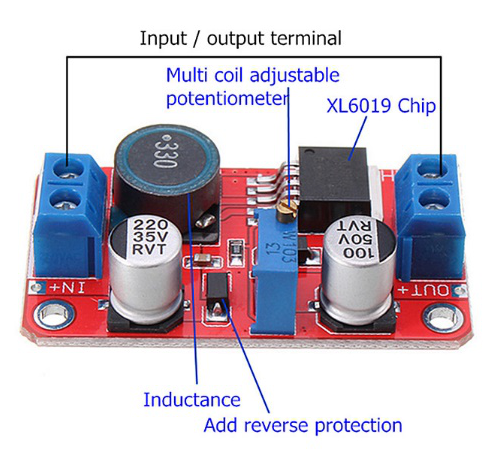
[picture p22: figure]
Diagram Description generated with very high confidence

Fig 2.11: Layout Of Xl6019 Dc To Dc Booster Module

2.12 5.5v 70ma SOLAR PANEL

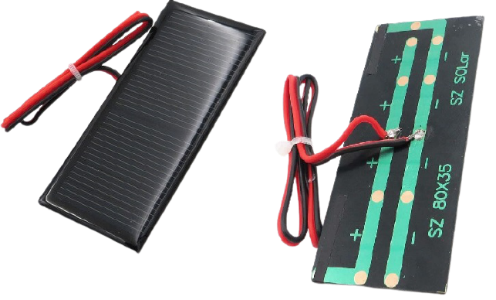
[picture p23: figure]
A picture containing text Description generated with very high confidence

5.5v 70ma Solar Panel is a device used to absorb the sun's rays and convert them into a 5.5v 70ma power source.

Fig 2.12: Layout of 5.5v 70ma Solar Panel

Chapter 3

DESIGN AND METHODOLOGY

3.1 Research Methodology

Fig 3.1 below is a flow chart diagram which explains the methods applied to achieve this project work.

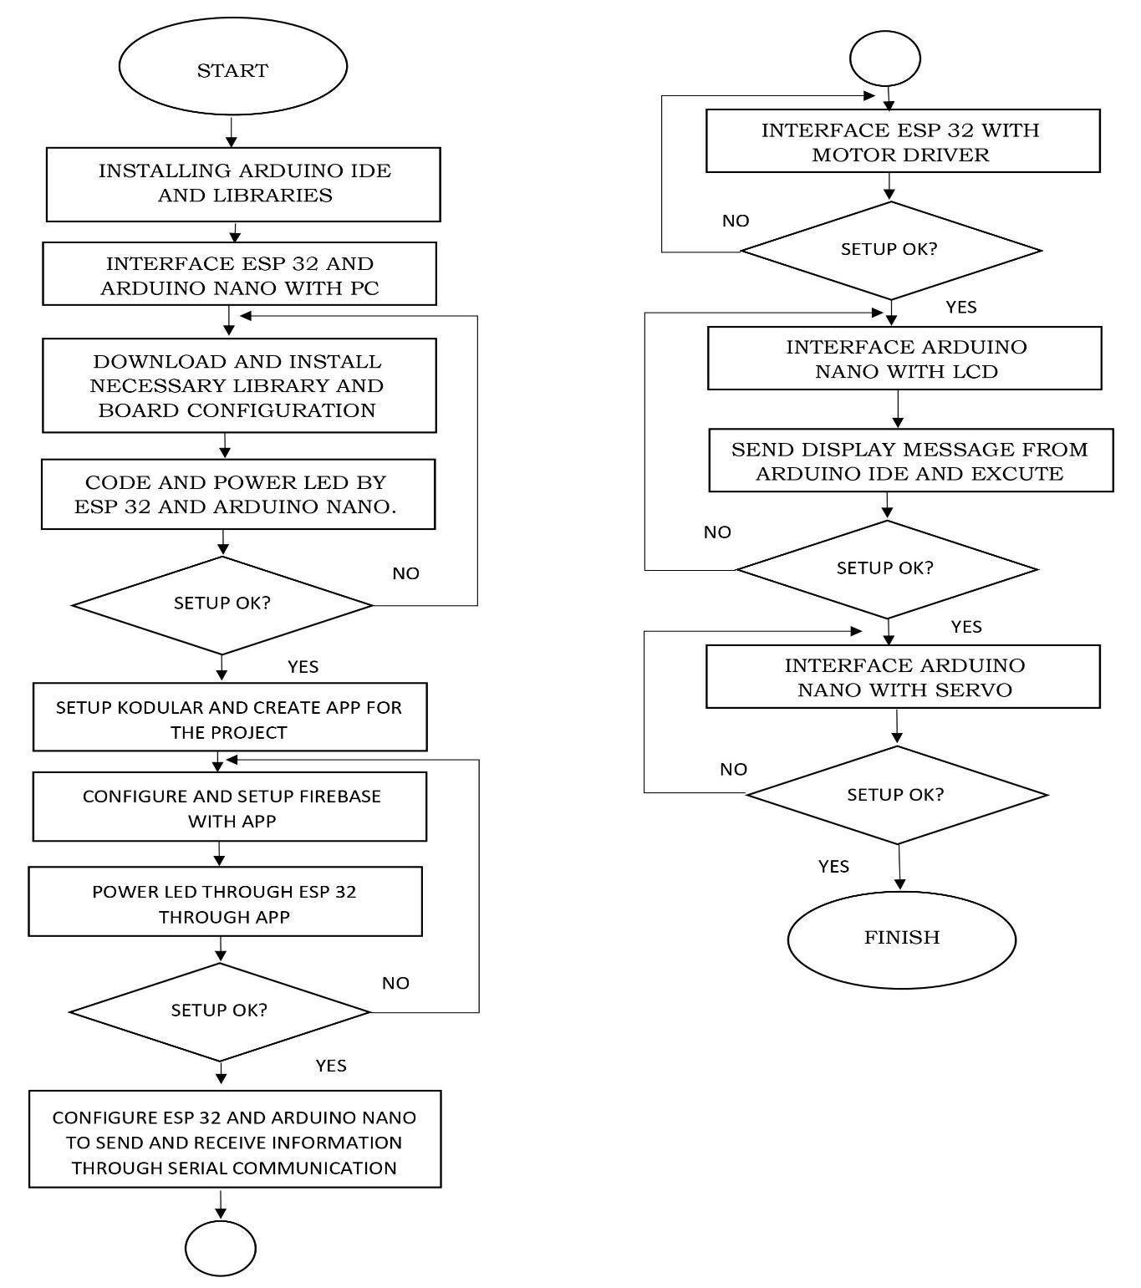
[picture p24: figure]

Fig 3.1: Flow Chart of Research Methods

This project topic was selected based on studying the present Agricultural Research Technology Systems in Nigeria, before recommending a more practical approach. The circuit design for the system was laid, required hardware needed for the project were listed and ordered.

Hard connection and programming were successfully done after being conversant with the Arduino Ide and its language. After the setup was done and tested okay. I connected Esp 32 Cam, Arduino Nano, Bluetooth configuration with the app. Once the system is set up, it would be a replica of the block diagram and circuit diagram below:

3.2 TOOLS

This section involves the hardware and software materials that were used during this project.

    3.2.1 Hardware
i. Esp 32 Cam
ii. Arduino Nano
iii. 16 x 2 i2c LED
iv. Vero Board
v. L298N Motor Driver
vi. Connecting wires
vii. 18650 Lithium Battery Case
viii. 18650 Lithium Battery
ix. Servo: Mg996r Servo and Mg995 Servo
x. 12v330 Geared Motor
xi. Battery Indicator Module
xii. Switch
xiii. Mobile Device
  3.2 SOFTWARE:
i. ARDUINO IDE
ii. KODULAR
iii. WEB BROWSER
  3.3 SYSTEM DESIGN (BLOCK DIAGRAM)

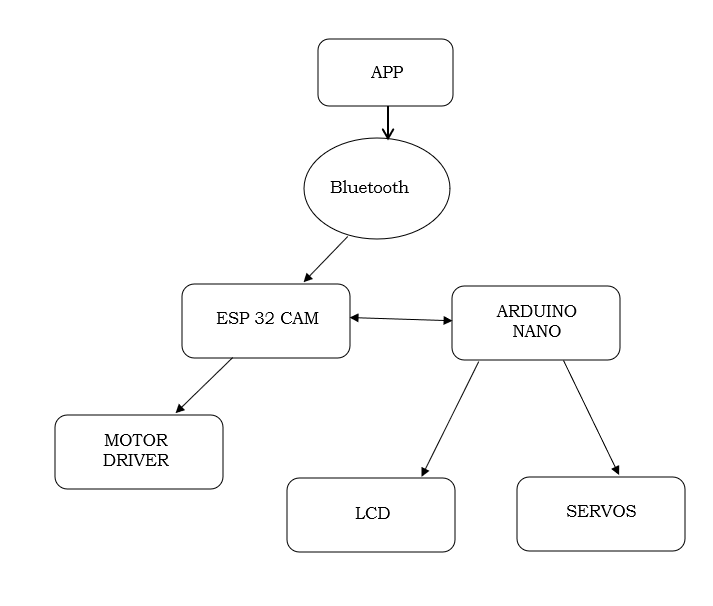
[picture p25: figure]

Fig 3.3.1: Block Diagram

The total voltage supplied to the system is 11v which is divided into 5v which is required to power both the Esp 32 Cam and Arduino Nano and 5 – 7v which is required to power the Servo and 6 -11v which is required to power the Motor.

The App will send and receive information through the Bluetooth, The Esp 32 cam will receive commands (instructions) from Bluetooth transmitter and send some information meant for the Arduino Nano, Arduino Nano controls the LCD and Servo while the Esp 32 Cam controls the Motor Driver.

Below is the pictorial circuit diagram:

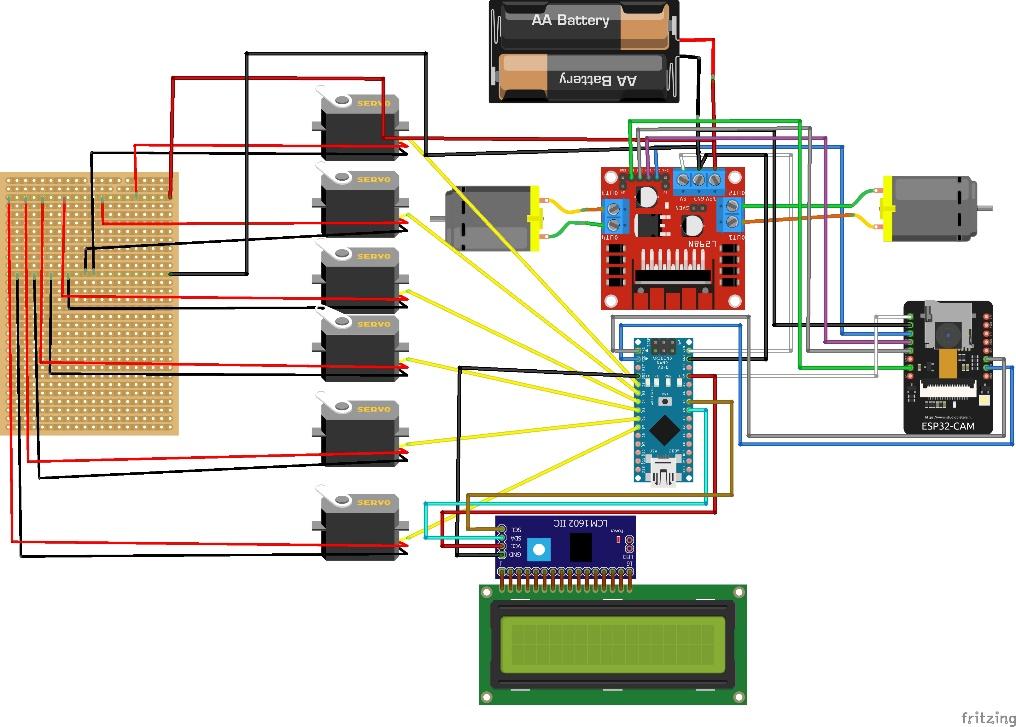
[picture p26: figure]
Diagram, schematic Description generated with very high confidence

Fig 3.3.2: Pictorial Circuit Diagram

3.4 CIRCUIT DIAGRAM DESIGN:

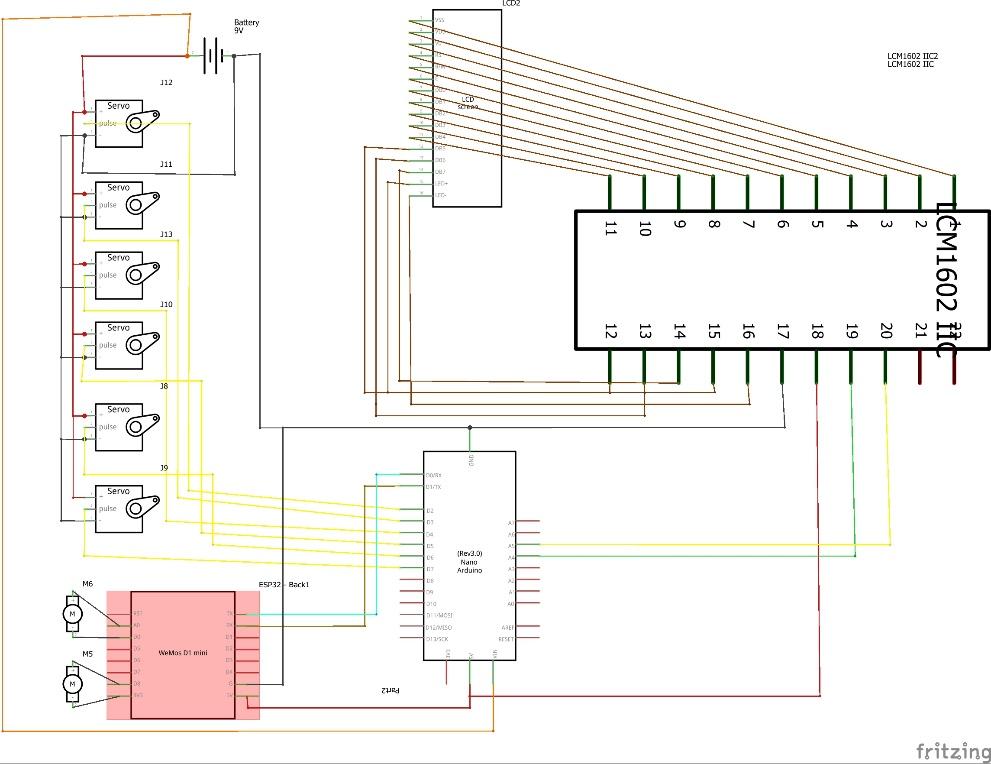
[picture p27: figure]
Diagram, schematic Description generated with very high confidence

Fig 3.4: Circuit Diagram

3.5 METHODOLOGY:

3.5.1: SETTING UP THE ESP 32 CAM AND ARDUINO NANO ON ARDUINO IDE

When Arduino Nano is connected to the system and Esp 32 Cam is connected via FTDI Module, if the PC cannot recognize it, you have to download and install proper drivers for the devices. After plug in your boards, download Arduino IDE and run. On the IDE interface, go to the file and then in the preferences and put this link in https://raw.githubusercontent.com/espressif/arduino-esp32/gh-pages/packages_esp32_index.json and then to install the Esp 32 board into the Arduino Ide navigate to the tools, then navigate to board, click on board manager, then search for Esp 32 cam, select the latest version for the board and install, then navigate to sketch under include library navigate manage libraries and search for Esp 32, locate the Esp 32 library and install, if the Esp 32 library isn’t in the search list, Open web browser and search for Esp 32 library and download, navigate to sketch, under include library click on Add .zip library to install the downloaded library. After installing the board and library, under tools, navigate to board and select your desired board which might be AI Thinker Esp32-Cam or Arduino Nano. Make sure your port number is the same as where your board is connected, reflect on the port section under tools of the Arduino Ide. Other libraries needed for the project must be downloaded. Restart the pc and you are set to program.

3.5.2: BUILDING THE APP ON KODULAR

Open a web browser and type kodular.io on the search bar, Go to the Kodular Creator page. A Login screen will be displayed to you. Continue by logging in.

After that, you'll be directed to the Projects page. To start a new project, click the New Project button. You are free to use whatever name you choose.

Next should be selected. The project will be created, and you will be directed to your project's Designer page. For testing your app while it's being developed, download Kodular App Companion on your mobile phone and connect the companion to kodular for better testing of the app.

3.5.4: CONNECTING THE I2C LCD TO THE ARDUINO NANO

A 16 x 2 LCD screen was also used in the project. The Gnd and Vcc pin on the I2c were connected to the Gnd and 5v pin of the Arduino Nano respectively and SDA and SCL of the I2c were connected to A4 and A5 pins of the Arduino Nano respectively as shown in the picture below:

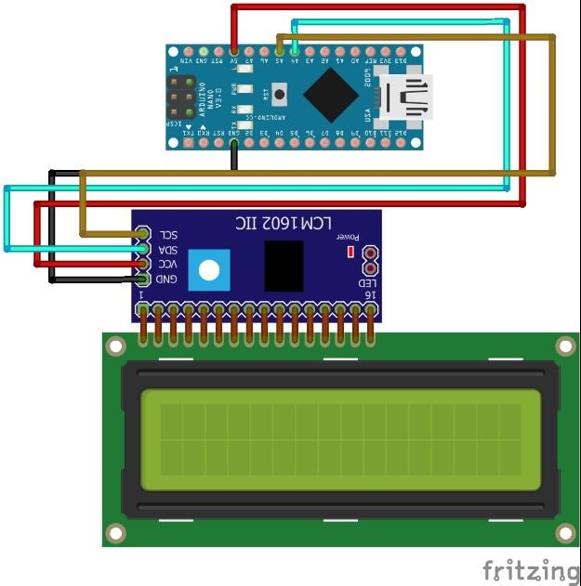
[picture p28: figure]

Fig 3.5.4 Connecting The I2c Lcd To The Arduino Nano

The liquid crystal I2c library from the Arduino Ide library manager was installed and included in the code programming. The I2c Module was interfaced to the LCD by soldering the 16pins of the LCD to the I2c module respectively converting the 16pins to four pins, which are the Vcc, Gnd, Sda and Scl.

3.5.5: CONNECTING SERVO TO THE ARDUINO NANO

Servo Motor operates on pulse signal, from 0 to 180 degrees when the pulse is at 0m/s is at 0 degree, 1.5m/s is 90 degrees, and when the pulse is at 2m/s is at 180 degrees. It’s doesn’t requires any external library on Arduino Ide

It’s has the 3 terminals: Positive pin (Red) goes to the 5v pin on the Arduino, Negative Pin (Black) goes to the Gnd pin on the Arduino, while the Pulse pin (Orange/Yellow) is connected to pin D2 to D7. As shown below:

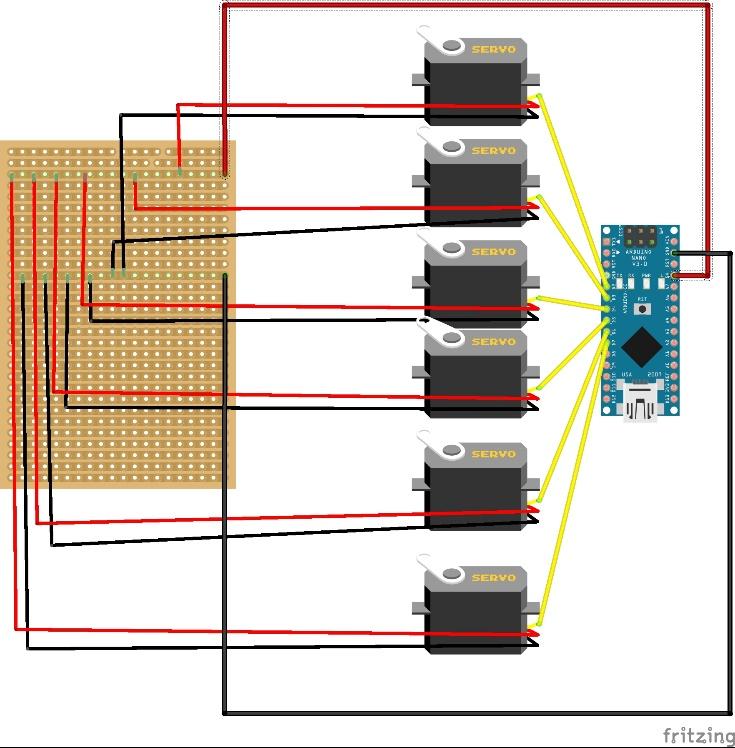
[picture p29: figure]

Fig 3.5.5: Connecting Servo to the Arduino Nano

3.5.6: CONNECTING THE MOTOR CONNECTED TO MOTOR DRIVER TO ESP 32 CAM

Motor drivers act as an interface between the motors and Esp 32 Cam, which send the instructions received from the Esp 32 to the motors. The controller can take up to 2 motors. Plug one motor into the terminal labelled out1 and out2 and plug the second motor into the terminal labelled out3 and out4. Then, the row of pins on the bottom right of the L298N controls the speed and direction of the motors. in1 and in2 control the direction of the motor connected to out1 and out2. in3 and in4 control the direction of the motor connected to out3 and out4. The L298N can be power with 12v by plugging your power source into the pin on the L298N labelled "12v". The pin labelled "5v" is a 5v output that you can use to power your Arduino. Now write the code. Setting in1 to high and in2 to low will cause the left motor to turn a direction. Setting in1 to low and in2 to high will cause the left motor to spin in the other direction, and the same applies to in3 and in4.

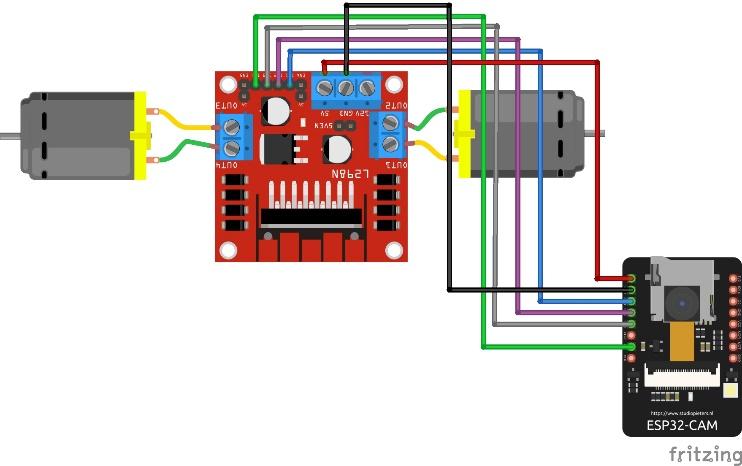
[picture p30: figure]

Fig 3.5.6: Pictorial Circuit Diagram of Connecting the Motor connected to Motor Driver to Esp 32 Cam

3.5.7: PROGRAM CODE

Below is the code used to make this system work:

Program Code for ESP 32 Cam:

#include <BluetoothSerial.h>

#if !defined(CONFIG_BT_ENABLED) || !defined(CONFIG_BLUEDROID_ENABLED)

#error Bluetooth is not enabled! Please run `make menuconfig` to and enable it

#endif

BluetoothSerial SerialBT;

String readString;

#define in1 14 //Connect in1 to pin 14

#define in2 15 //Connect in2 to pin 15

#define in3 13 //Connect in3 to pin 13

#define in4 12 //Connect in4 to pin 12

#define in5 4 //Connect in5 to pin 4 LED

void setup()

{

Serial.begin(115200);

// Bluetooth device name

SerialBT.begin("ZetaBot");

Serial.println("The device started, now you can pair it with bluetooth!");

pinMode(in1, OUTPUT); //Set in1 as an output

pinMode(in2, OUTPUT); //Set in2 as an output

pinMode(in3, OUTPUT); //Set in3 as an output

pinMode(in4, OUTPUT); //Set in4 as an output

pinMode(in5, OUTPUT); //Set pin 4 as an output

digitalWrite(in1, LOW); //Switch in1 off

digitalWrite(in2, LOW); //Swtich in2 off

digitalWrite(in3, LOW); //Switch in3 off

digitalWrite(in4, LOW); //Swtich in4 off

digitalWrite(in5, LOW); //Swtich Pin 4 off

}

void loop()

{

while (SerialBT.available()) //Check if there are available bytes to read

{

delay(10); //Delay to make it stable

char c = SerialBT.read(); //Conduct a serial read

if (c == '#') {

break; //Stop the loop once # is detected after a word

}

readString += c; //Means readString = readString + c

}

if (readString.length() > 0)

{

SerialBT.println(readString);

if (readString == "4") {

digitalWrite(in1, 1); // RF 14

digitalWrite(in2, 0); // RB 15

digitalWrite(in3, 0); // LF 13

digitalWrite(in4, 1); // LB 12

Serial.write(53);

delay(10);

}

else if (readString == "6") {

digitalWrite(in1, 0);

digitalWrite(in2, 1);

digitalWrite(in3, 1);

digitalWrite(in4, 0);

Serial.write(54);

delay(10);

}

else if (readString == "8") {

digitalWrite(in1, 1);

digitalWrite(in2, 0);

digitalWrite(in3, 1);

digitalWrite(in4, 0);

Serial.write(51);

delay(10);

}

else if (readString == "2") {

digitalWrite(in1, 0);

digitalWrite(in2, 1);

digitalWrite(in3, 0);

digitalWrite(in4, 1);

Serial.write(52);

delay(10);

}

else if (readString == "5") {

digitalWrite(in1, 0);

digitalWrite(in2, 0);

digitalWrite(in3, 0);

digitalWrite(in4, 0);

Serial.write(55);

delay(10);

}

// Tank Light

else if (readString == "9") {

digitalWrite(in5, HIGH);

delay(10);

}

else if (readString == "3") {

digitalWrite(in5, LOW);

delay(10);

}

// Arm

// Servo 1 Roll Right

else if (readString == "17") {

Serial.write(31);

delay(10);

}

// Servo 2 Roll Left

else if (readString == "16") {

Serial.write(32);

delay(10);

}

// Servo 2 Pitch Right

else if (readString == "19") {

Serial.write(33);

delay(10);

}

// Servo2 Pitch Left

else if (readString == "18") {

Serial.write(34);

delay(10);

}

// Servo 3 Grip Right

else if (readString == "21") {

Serial.write(35);

delay(10);

}

// Servo3 Grip Left

else if (readString == "20") {

Serial.write(36);

delay(10);

}

// Servo 4 Elbow Right

else if (readString == "23") {

Serial.write(37);

delay(10);

}

// Servo 4 Elbow Left

else if (readString == "22") {

Serial.write(38);

delay(10);

}

// Servo 5 Shoulder Right

else if (readString == "25") {

Serial.write(39);

delay(10);

}

// Servo 5 Shoulder Left

else if (readString == "24") {

Serial.write(40);

delay(10);

}

// Servo 6 Waist Right

else if (readString == "27") {

Serial.write(41);

delay(10);

}

// Servo 6 Waist Left

else if (readString == "26") {

Serial.write(42);

delay(10);

}

}

readString = "";

}

Program Code for ESP 32 Cam Live Stream:

Go to File – Examples - ESP 32 – Camera – CameraWebServer

Select Camera Model as CAMERA_MODEL_AI_THINKER

Change SSID and SSID Password

Note the Ip address on Serial Monitor on serial 115200

Program Code for Arduino Nano:

#include "LiquidCrystal_I2C.h"

#include <SPI.h> // to read from serial pin

LiquidCrystal_I2C lcd(0x27, 16, 2);

#include <Servo.h>

#include <SoftwareSerial.h>

String message0 = String("HELLO, I'M ZETABOT");

String message1 = String("Oke Iyanuoluwa Enoch");

String message2 = String("Mat No:- 1701326/17BD005101");

String message4 = String("Connecting ...");

String message5 = String("Bluetooth and Wifi Connected ");

int length0;

int length1;

int length2;

int length4;

int length5;

Servo servo01;

Servo servo02;

Servo servo03;

Servo servo04;

Servo servo05;

Servo servo06;

int servo1Pos, servo2Pos, servo3Pos, servo4Pos, servo5Pos, servo6Pos; // current position

int servo1PPos, servo2PPos, servo3PPos, servo4PPos, servo5PPos, servo6PPos; // previous position

int servo01SP[50], servo02SP[50], servo03SP[50], servo04SP[50], servo05SP[50], servo06SP[50]; // for storing positions/steps

int speedDelay = 20;

int index = 0;

String dataIn = "";

void setup()

{

Serial.begin(115200);

// Lcd

lcd.init();

lcd.backlight();

length0 = message0.length();

length1 = message1.length();

length2 = message2.length();

length4 = message4.length();

length5 = message5.length();

// Introduction Message

for (int i = 0; i < length0; i++)

{

ClearRow(0);

lcd.print(message0.substring(i, i + 15));

delay(500);

}

for (int i = 0; i < length1; i++)

{

ClearRow(0);

lcd.print(message1.substring(i, i + 15));

delay(500);

}

for (int i = 0; i < length2; i++)

{

ClearRow(1);

lcd.print(message2.substring(i, i + 15));

delay(500);

}

servo01.attach(5);

servo02.attach(6);

servo03.attach(7);

servo04.attach(4);

servo05.attach(3);

servo06.attach(2);

delay(20);

// Send 90 degrees to servos before assembling servos

// Robot arm initial position

servo1PPos = 65;

servo01.write(servo1PPos);

delay(300);

servo2PPos = 90; //50

servo02.write(servo2PPos);

delay(300);

servo3PPos = 80;

servo03.write(servo3PPos);

delay(300);

servo4PPos = 20;

servo04.write(servo4PPos);

delay(300);

servo5PPos = 120;

servo05.write(servo5PPos);

delay(300);

servo6PPos = 50;

servo06.write(servo6PPos);

delay(300);

}

void loop()

{

// Tank Messages

// Forward Message

if (Serial.available() > 0) {

if (Serial.read() == 51) {

lcd.clear();

lcd.setCursor(0, 0);

lcd.print("Moving Forward");

delay(100);

}

}

// Backward Message

if (Serial.available() > 0) {

if (Serial.read() == 52) {

lcd.clear();

lcd.setCursor(0, 0);

lcd.print("Moving Backward");

delay(100);

}

}

// Left Message

if (Serial.available() > 0) {

if (Serial.read() == 53) {

lcd.clear();

lcd.setCursor(0, 0);

lcd.print("Moving Left");

delay(100);

}

}

// Right Message

if (Serial.available() > 0) {

if (Serial.read() == 54) {

lcd.clear();

lcd.setCursor(0, 0);

lcd.print("Moving Right");

delay(100);

}

}

// Stop Message

if (Serial.available() > 0) {

if (Serial.read() == 55) {

lcd.clear();

lcd.setCursor(0, 0);

lcd.print("Moving Stopped");

delay(100);

}

}

// Arm Code

// Roll

if (Serial.available() > 0) {

if (Serial.read() == 31) {

servo1PPos = servo1PPos + 20;

servo01.write(servo1PPos);

delay(10);

lcd.clear();

lcd.setCursor(0, 0);

lcd.print("Roll Right");

}

}

if (Serial.available() > 0) {

if (Serial.read() == 32) {

servo1PPos = servo1PPos - 20;

servo01.write(servo1PPos);

delay(10);

lcd.clear();

lcd.setCursor(0, 0);

lcd.print("Roll Left");

}

}

// Pitch

if (Serial.available() > 0) {

if (Serial.read() == 33) {

servo2PPos = servo2PPos + 20;

servo02.write(servo2PPos);

delay(10);

lcd.clear();

lcd.setCursor(0, 0);

lcd.print("Pitch Right");

}

}

if (Serial.available() > 0) {

if (Serial.read() == 34) {

servo2PPos = servo2PPos - 20;

servo02.write(servo2PPos);

delay(10);

lcd.clear();

lcd.setCursor(0, 0);

lcd.print("Pitch Left");

}

}

// Grip

if (Serial.available() > 0) {

if (Serial.read() == 35) {

servo3PPos = servo3PPos + 20;

servo03.write(servo3PPos);

delay(10);

lcd.clear();

lcd.setCursor(0, 0);

lcd.print("Grip Right");

}

}

if (Serial.available() > 0) {

if (Serial.read() == 36) {

servo3PPos = servo3PPos - 20;

servo03.write(servo3PPos);

delay(10);

lcd.clear();

lcd.setCursor(0, 0);

lcd.print("Grip Left");

}

}

// Elbow

if (Serial.available() > 0) {

if (Serial.read() == 37) {

servo4PPos = servo4PPos + 20;

servo04.write(servo4PPos);

delay(10);

lcd.clear();

lcd.setCursor(0, 0);

lcd.print("Elbow Right");

}

}

if (Serial.available() > 0) {

if (Serial.read() == 38) {

servo4PPos = servo4PPos - 20;

servo04.write(servo4PPos);

delay(10);

lcd.clear();

lcd.setCursor(0, 0);

lcd.print("Elbow Left");

}

}

// Shoulder

if (Serial.available() > 0) {

if (Serial.read() == 39) {

servo5PPos = servo5PPos + 20;

servo05.write(servo5PPos);

delay(10);

lcd.clear();

lcd.setCursor(0, 0);

lcd.print("Shoulder Right");

}

}

if (Serial.available() > 0) {

if (Serial.read() == 40) {

servo5PPos = servo5PPos - 20;

servo05.write(servo5PPos);

delay(10);

lcd.clear();

lcd.setCursor(0, 0);

lcd.print("Shoulder Left");

}

}

// Waist

if (Serial.available() > 0) {

if (Serial.read() == 41) {

servo6PPos = servo6PPos + 20;

servo06.write(servo6PPos);

delay(10);

lcd.clear();

lcd.setCursor(0, 0);

lcd.print("Waist Right");

}

}

if (Serial.available() > 0) {

if (Serial.read() == 42) {

servo6PPos = servo6PPos - 20;

servo06.write(servo6PPos);

delay(10);

lcd.clear();

lcd.setCursor(0, 0);

lcd.print("Waist Left");

}

}

}

void ClearRow(int rowNum)

{ lcd.setCursor(0, rowNum);

lcd.print(" ");

lcd.setCursor(0, rowNum);

}

Kodular Code for Project Mobile Application:

Robotic Tank Controller Code:

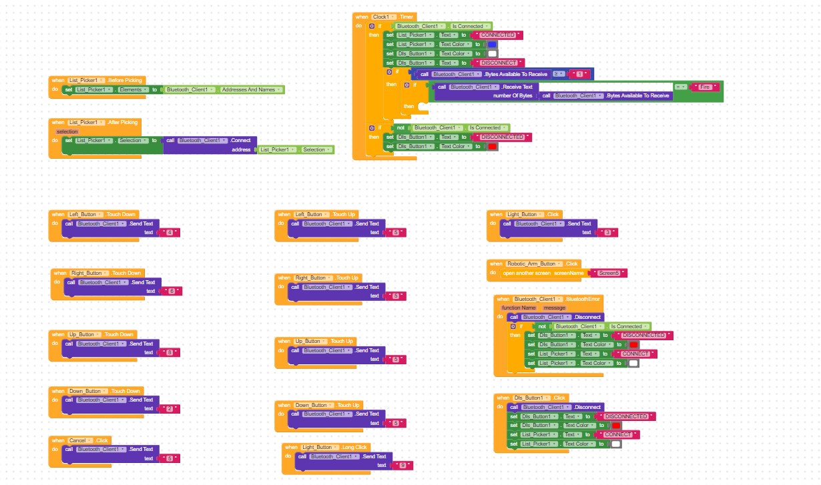
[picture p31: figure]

Robotic Arm Controller Code:

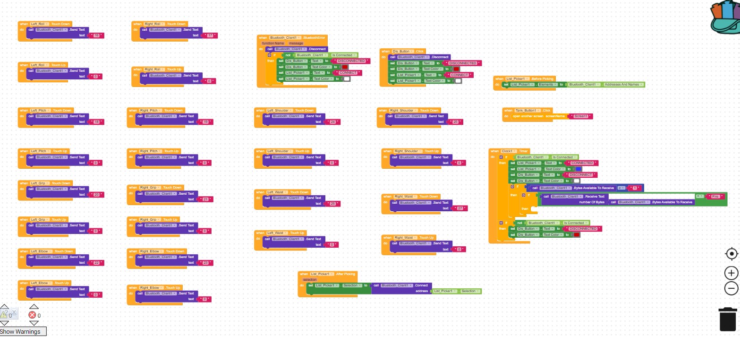
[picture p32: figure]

CHAPTER 4

RESULTS AND DISCUSSIONS

4.1 RESULTS AND DISCUSSION

The constructed project was made according to the Pictorial Circuit Diagram and Circuit Diagram in Fig 3.3.2 and Fig 3.4 respectively, which produced expected results.

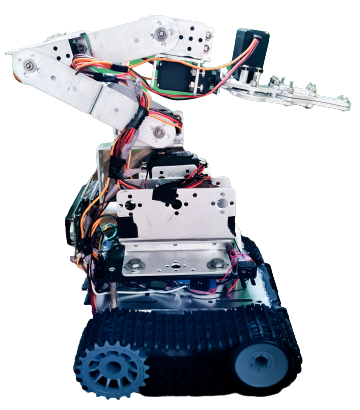
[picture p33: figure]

Fig 4.1 Final Constructed Project Result

The “LMU WIFI” was used to connect Esp 32 Cam to the internet and the laptop was connected to the WIFI providing a constant WIFI SSID and WIFI Password for a live stream footage. The app is connected to the project through a Bluetooth. Every output from the project is monitored through the LCD screen. The appliances are connected according to the circuit diagrams. The Tank is power by 3 x 3.7v lithium battery providing a total of 11v, and the Arm is power by 2 x 3.7v lithium battery providing a total of 7.4v, voltage connected to the project.

This project is operating as stated in this report. Instructions are sent and received by the Esp 32 Cam through inbuilt Bluetooth feature and share received instruction across the other components in the project. The live video footage from the Esp 32 Cam is monitor from the laptop screen using a ip address. The Ip address is the internet protocol address of the Esp 32 Cam which is found on the serial monitor of the Arduino Ide as Esp 32 Cam is connected to a network.

The App is sectioned in two ways, the first part of the app controls the Tank while the second part of the app control the Arm. The directions on the app is used to control the tank wheel in different directions. The Arm app section is used to control each joint part of the Arm.

CHAPTER 5

CONCLUSION AND RECOMMENDATION

5.1 RECOMMENDATION

The project is not basically for Robotic Greenhouse Farming, but also in any area of field research purpose. Network (Wifi) is something that is very important in this project makeup. It is recommended that when setting this project, a strong network or Wifi signal is to be used or a separate network connection should be set up for the project alone, a strong network connection is require for the live stream footage from the Esp 32 Cam.

5.2 CONCLUSION

I successfully designed and implemented the proposed low-cost robot, as explained in this project report. The mobile app is user friendly and self-explanatory, once the mobile is connected to the robot is shows connected and the robot displaying a welcome message indicating the robot is still booting. With this project being designed and implemented, a user-friendly, scalable, open-source and low-cost agrotechnology is believed to have been achieved.

Although, the project was initially planned to be operated over the Internet instead of Bluetooth Connection, this was due to lack of strong internet and availability of materials need for the seamless transmission.

REFERENCES

1. What Is Robotics? (2009, November 9). Retrieved from https://www.nasa.gov/audience/forstudents/k-4/stories/nasa-knows/what_is_robotics_k4.html
2. Robots in The Lab. (2012, May 10). Automate. Retrieved from https://www.automate.org/industry-insights/robots-in-the-lab
3. Robotics in Manufacturing. (n.d.). Acieta. Retrieved from https://www.acieta.com/why-robotic-automation/robotics-manufacturing/
4. Everything You Need to Know About Robotic Arms. (n.d.). Retrieved from https://ie.rs-online.com/web/generalDisplay.html?id=ideas-and-advice/robotic-arms-guide
5. 6 Common Applications for Robots in Automotive Manufacturing. (n.d.). Genesis Systems. Retrieved from https://www.genesis-systems.com/blog/robots-automotive-manufacturing-top-6-applications
6. A Problem Statement of Robotics Technologies Information Technology Essay. (n.d.). Retrieved from https://www.ukessays.com/essays/information-technology/a-problem-statement-of-robotics-technologies-information-technology-essay.php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
7. Robotics: A Brief History from https://cs.stanford.edu/people/eroberts/courses/soco/projects/1998-99/robotics/history.html
8. Arduino Development Boards. (n.d.). Retrieved from https://eu.mouser.com/applications/open-source-arduino/
9. Getting Started with ESP32 CAM Board & Video Streaming Over WiFi. (n.d.). How To Electronics from https://how2electronics.com/getting-started-with-esp32-cam-board-video-streaming-over-wifi/
10. ESP32-CAM - Getting Started & Solving Common Problems. (n.d.). DroneBot Workshop. Retrieved from https://dronebotworkshop.com/esp32-cam-intro/
11. L298N Motor Driver Board - Geeetech Wiki. (n.d.). Retrieved from https://www.geeetech.com/wiki/index.php/L298N_Motor_Driver_Board
12. Motor Driver Module-L298N - Wiki. (n.d.). Retrieved from http://wiki.sunfounder.cc/index.php?title=Motor_Driver_Module-L298N
13. DC Motor Direction Control Using Arduino Uno with L298 Driver. (n.d.). Retrieved from https://www.ukessays.com/essays/engineering/dc-motor-direction-control-using-arduino-uno-with-l298-driver.php
14. Servo Motors - Arduino - Wiki.nus. (n.d.). Retrieved from https://wiki.nus.edu.sg/display/Arduino/Servo+Motors#ServoMotors-SG90MicroServo
15. For, E. (2021, July 17). 16x2 LCD Pinout Diagram | Interfacing 16x2 LCD With Arduino. Electronics for You. Retrieved from https://www.electronicsforu.com/technology-trends/learn-electronics/16x2-lcd-pinout-diagram
16. Kodular (2021, May 30). Everybody Wiki Bios & Wiki. Retrieved from https://en.everybodywiki.com/Kodular

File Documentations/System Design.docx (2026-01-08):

APP

Bluetooth

ESP 32 CAM

MOTOR DRIVER

SERVOS

LCD

ARDUINO NANO

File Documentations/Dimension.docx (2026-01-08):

Tank: -

Basic Parameters:

- Material: Aluminum Alloy
- Size: about 175*180*85mm (Length* weight * height)
- Weight: 0.5kg
- Color: Black
- Track: Plastic
- Type of Motor: 12V/330rpm Motor
- Load: About 3KG

Robotic 6DOF(6 Degree of Freedom) Clamp Claw: -

Features:

- Material: Aluminum Alloy
- Rotation angle of 180 degrees
- Radius of gyration: 355mm
- Height: 4600mm (holder closed)
- Clamp Max open is 55mm
- Holder of the widest distance: 98mm
- Color: Silver

3D Front Casing Dimension

12.9cm x 8.9cm x 4.6cm

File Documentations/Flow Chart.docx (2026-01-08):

START

INTERFACE ESP 32 WITH MOTOR DRIVER

INTERFACE ESP 32 AND ARDUINO NANO WITH PC

INSTALLING ARDUINO IDE AND LIBRARIES

NO

SETUP OK?

YES

INTERFACE ARDUINO NANO WITH LCD

DOWNLOAD AND INSTALL NECESSARY LIBRARY AND BOARD CONFIGURATION

CONFIGURE ESP 32 AND ARDUINO NANO TO SEND AND RECEIVE INFORMATION THROUGH SERIAL COMMUNICATION

NO

NO

YES

YES

FINISH

SETUP OK?

INTERFACE ARDUINO NANO WITH SERVO

SETUP OK?

SEND DISPLAY MESSAGE FROM ARDUINO IDE AND EXCUTE

YES

SETUP KODULAR AND CREATE APP FOR THE PROJECT

CONFIGURE AND SETUP FIREBASE WITH APP

POWER LED THROUGH ESP 32 THROUGH APP

SETUP OK?

NO

SETUP OK?

YES

NO

CODE AND POWER LED BY ESP 32 AND ARDUINO NANO.

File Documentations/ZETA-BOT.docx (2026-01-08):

ZETA-BOT

Robotic 6DOF Arm and Robotic Tank Operation: -

Is a smart robot that is programmed to execute a specific task or job quickly, efficiently, and extremely accurately.

A typical industrial robot arm includes a series of joints, articulators and manipulators that work together to closely resemble the motion and functionality of a human arm

Areas of Application:

Robotic arms can be used for all manner of industrial production, processing and manufacturing roles - any task in which extremely precise, fast and repeatable movements are required

- Agriculture: -
- Nursery Planting: There is a rising need for nursery automation. Companies like HETO Agrotechnics and Harvest Automation provide automation solutions for seeding, potting and warehousing living plants in greenhouses.
- Crop Seeding: Autonomous precision seeding combines robotics with geomapping. A map is generated which shows the soil properties (quality, density, etc) at every point in the field. The tractor, with robotic seeding attachment, then places the seeds at precise locations and depths so that each has the best chance of growing.
- Fertilizing and Irrigation: Irrigating and fertilizing crops has traditionally used a lot of water is quite inefficient. Robot-Assisted Precision Irrigation can reduce wasted water by targeting specific plants. Ground robots autonomously navigate between rows of crop and pour water directly at the base of each plant.
- Crop Weeding and Spraying: Spraying pesticides and weed killers onto fields is not only wasteful, it can severely harm the environment. Robots provide a much more efficient method. The concept of micro-spraying could significantly reduce the amount of herbicide used in crop growing. Micro-spraying robots use computer vision technology to detect weeds and then spray a targeted drop of herbicide onto them. AG BOT II is a solar powered robot which uses this technique.
- Milking: using collaborative robots to help in the milking process on dairy farms. This case study by Universal Robots shows how a UR5 can be used to spray disinfectant on the cow's udders in preparation for milking.
- Astronaut:
- A small robotic arm could be used inside the station. A robot like that helps in an emergency. If an astronaut were seriously hurt, a doctor on Earth could use the arm to perform surgery.
- Robots also can be used as scouts to check out new areas to be explored. Scout robots can take photographs and measure the terrain. This helps scientists and engineers make better plans for exploring. Scout robots can be used to look for dangers and to find the best places to walk, drive or stop. This helps astronauts work more safely and quickly. Having humans and robots work together makes it easier to study other worlds.
- Laboratories:
- Clinical laboratories use robotic systems for test tube sorting in a wide range of tasks such as dispensing, labeling and capping.” Robots handle test tubes and flasks, sort test tubes and have a major role in drug discovery.
- Mobile robots providing on-demand and scheduled transport of laboratory specimens and pharmaceuticals transport laboratory specimens.
- Manufacturing:
- Robots protect workers from repetitive, mundane and dangerous tasks, while also creating more desirable jobs, such as engineering, programming, management and equipment maintenance.
- Robots free up manpower to let companies maximize workers’ skills in other areas of the business.
- Industrial automation:
- Collaborative Robots: These collaborative robots are built to work together with other robots, on enormous assembly lines. Robots must collaborate between handling and welding robots to make such assembly lines function properly.
- Robotic Painting: Professional painters are difficult to find, and the job is a highly toxic one. This makes it perfect for robots, because the paint job needs to be highly consistent over a large area of paint and reducing the amount of wasted material can add up to quite a bit of savings over time.
- Robotic Assembly: In many automotive plants, robots are assembling smaller components like pumps and motors at high speeds. Often, robots are performing tasks like windshield installation and wheel mounting to increase throughput.

Dimension:

Tank: -

Basic Parameters:

- Material: Aluminum Alloy
- Size: about 175*180*85mm (Length* weight * height)
- Weight: 0.5kg
- Color: Black
- Track: Plastic
- Type of Motor: 12V/330rpm Motor
- Load: About 3KG

Robotic 6DOF(6 Degree of Freedom) Clamp Claw: -

Features:

- Material: Aluminum Alloy
- Rotation angle of 180 degrees
- Radius of gyration: 355mm
- Height: 4600mm (holder closed)
- Clamp Max open is 55mm
- Holder of the widest distance: 98mm
- Color: Silver

Area of Zeta-Bot Application:

- To be used for automated harvesting of crops and fruit on soft stem or branches.
- To be used as scouts to check out new areas to be explored. It can take photographs and measure the terrain. This helps scientists and engineers make better plans for exploring both on earth and space.
- To work together with other robots, on enormous assembly lines and welding to make such assembly lines function properly.

Oke Iyanuoluwa Enoch: 17BD005101/1701326

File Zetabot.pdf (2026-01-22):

# Design and Construction of a Mobile Control Robot Arm on a Robotic Wheel

Oke Iyanuoluwa Enoch
Lecturer: Dr. P.K Olulope
B.Eng. Electrical and Information Engineering College of Science and Engineering Landmark University, Omu-aran, Nigeria oke.iyanuoluwa@lmu.edu.ng, oke.iyanuoluwa12@gmail.com

Abstract—This paper presents the design, development, and implementation of an innovative mobile robotic system integrating wireless vision streaming, multi-axis articulated manipulation, and distributed microcontroller architecture. The system comprises a tank-wheeled mobile platform equipped with an ESP32-CAM module for real-time video surveillance and an Arduino Nano controlled six-degree-of-freedom robotic arm. The architecture employs a novel dual microcontroller approach with inter-device serial communication, enabling parallel processing of mobility control and manipulation tasks. A custom Android application provides intuitive remote operation through Bluetooth connectivity. The platform demonstrates significant advancement in low-cost robotics by achieving industrial grade functionality including live IP-based video streaming, LCD based operational feedback, and modular power management supporting solar charging integration. Experimental validation confirms successful wireless operation with real-time video latency under 200ms and precise manipulator positioning within ±2

◦
accuracy. The
system’s scalable architecture and open-source implementation present opportunities for applications in agricultural automation, hazardous environment inspection, educational robotics, and research deployment scenarios requiring cost-effective mobile manipulation capabilities.
Index Terms—Mobile robotics, ESP32 microcontroller, robotic manipulation, wireless control, embedded systems, IoT robotics, distributed computing, computer vision
I. INTRODUCTION
The convergence of mobile robotics, wireless communication, and embedded systems has created unprecedented opportunities for autonomous systems in various industrial and research applications. Traditional robotic platforms often require significant capital investment and specialised infrastructure, limiting their accessibility to educational institutions and small-scale research initiatives. This work addresses this gap by presenting a comprehensive robotic system that achieves advanced functionality through innovative integration of commercially available components and custom software architecture.
The ZETABOT system represents a significant advancement in accessible robotics technology through several key innovations. First, the implementation of distributed processing architecture across ESP32-CAM and Arduino Nano platforms enables concurrent execution of computationally intensive vision streaming and real-time servo control. Second, the wireless communication framework supporting both Bluetooth control and WiFi based video transmission demonstrates practical IoT integration. Third, the modular power management system incorporating lithium battery arrays with solar charging capability addresses the critical challenge of field deployment sustainability.
Contemporary applications requiring mobile manipulation including precision agriculture, disaster response robotics, warehouse automation, and educational STEM programs demand platforms that balance functionality, cost effectiveness, and ease of deployment. This research contributes to that objective by demonstrating that sophisticated capabilities including live video feedback, articulated manipulation, and wireless operation can be achieved within accessible budget constraints without compromising operational performance.
A. Research Motivation and Problem Statement
The primary motivation for this research stems from the identified need for cost effective robotic platforms in developing regions and educational contexts where access to commercial robotic systems remains prohibitively expensive. Traditional industrial robotic arms and mobile platforms typically require investments exceeding $10,000, placing them beyond the reach of most educational institutions and small scale agricultural operations. Furthermore, existing low cost alternatives often compromise on critical capabilities such as wireless operation, vision systems, or manipulation dexterity. Specific technical challenges addressed include: (1) achieving reliable wireless video streaming with minimal latency using constrained embedded hardware, (2) coordinating multiple servo actuators through resource limited microcontrollers,
(3) implementing robust Bluetooth communication protocols for real-time control, and (4) developing user friendly mobile interfaces that require minimal technical expertise. The solution presented herein demonstrates that these challenges can be overcome through innovative architectural decisions and careful component selection.
B. Research Objectives
The specific objectives of this research are:
- Design and implement a distributed microcontroller architecture optimising task allocation between mobility control and manipulation systems

- Develop a wireless communication framework supporting concurrent Bluetooth control and WiFi video streaming with latency suitable for real-time operation
- Engineer a six-degree-of-freedom robotic arm achieving precise positioning control through serial communication protocol
- Create an intuitive Android mobile application providing comprehensive system control and operational feedback
- Validate system performance through experimental testing of mobility, manipulation accuracy, communication reliability, and power consumption characteristics

II. LITERATURE REVIEW AND RELATED WORK

A. Evolution of Mobile Robotic Systems
Mobile robotics has undergone substantial evolution from early industrial applications to contemporary IoT enabled autonomous systems. Siegwart et al. established foundational principles of autonomous mobile robot design, emphasising the integration of sensing, actuation, and control within constrained computational environments [31]. Traditional mobile robotic platforms historically relied on centralised processing architectures employing single board computers or industrial controllers, limiting accessibility due to cost and complexity considerations.
Recent advancements in microcontroller technology, particularly the emergence of wireless enabled platforms such as the ESP32 family, have democratised mobile robotics development. These platforms integrate computational capability, wireless connectivity, and peripheral interfaces within compact, energy efficient packages suitable for battery operated mobile applications. The dual-core architecture of ESP32 processors enables concurrent task execution, addressing traditional bottlenecks in wireless communication and real-time control applications.
B. Distributed Control Architectures in Robotics Distributed control architectures represent a fundamental approach to managing complexity in robotic systems through task partitioning across multiple processing units. Jahn et al.
[15] present comprehensive concepts for modular distributed architectures in robotic systems, introducing the Operator Controller Module framework that hierarchically organises system components into distinct functional layers. Their work demonstrates that distributed architectures enable scalable system design, facilitate fault isolation, and optimise resource utilisation across heterogeneous processing platforms.
The advantages of distributed processing extend beyond mere computational load balancing. Research in industrial robotics demonstrates that segregating real-time control functions from higher level planning and communication tasks improves system responsiveness and determinism. This architectural approach aligns with the hierarchical control paradigm prevalent in advanced robotic systems, where lower level controllers manage immediate sensor actuator interactions while higher level processors handle strategic decision making and human interface functions.

Implementation of distributed architectures traditionally required specialised middleware and complex inter process communication frameworks. However, lightweight serial communication protocols offer pragmatic alternatives for resource constrained embedded systems. The simplicity of UART based command protocols enables reliable inter controller communication with minimal overhead, particularly suitable for applications not requiring high bandwidth data exchange between processing nodes.

C. ESP32 Based Robotic Applications

The ESP32 microcontroller family has gained substantial adoption in mobile robotics applications due to its combination of processing capability, wireless connectivity, and cost effectiveness. Research demonstrates diverse implementations ranging from autonomous navigation systems to teleoperated inspection platforms. Studies have explored voice controlled mobile robotics utilising ESP32’s processing capabilities for command recognition and wireless control [19].
The ESP32 CAM variant, integrating camera capabilities with wireless communication, has enabled surveillance and monitoring applications. Mobile surveillance platforms employing ESP32 CAM for real-time video streaming over WiFi networks demonstrate the feasibility of vision based robotics within embedded system constraints [17]. These implementations typically achieve frame rates of 15-20 fps at VGA resolution, adequate for human operated teleoperation and basic computer vision tasks.
Integration of ESP32 platforms with Android based mobile interfaces represents a common architectural pattern in IoT robotics. Bluetooth Serial Profile provides straightforward command transmission mechanisms, enabling rapid prototyping of control applications without complex network configuration [20]. Implementations demonstrate reliable operation at distances up to 10 meters with latency suitable for humanin-the-loop control applications, validating this approach for educational and research deployments.
D. Robotic Manipulator Design and Control

Robotic manipulator design encompasses mechanical configuration, actuator selection, and control algorithm implementation. Classical manipulator theory emphasises kinematic analysis for position and orientation control, with industrial applications typically requiring precise trajectory planning and force control capabilities. However, educational and demonstration platforms often employ simplified control schemes prioritising ease of implementation over absolute positioning accuracy.
Low cost manipulator implementations commonly utilise hobby servo motors for actuation, trading precision for affordability and simplicity. Standard hobby servos provide integrated position control through PWM signal interpretation, abstracting motor driver complexity and enabling straightforward microcontroller interfacing. Multi DOF arms employing serial chains of servo actuators can achieve workspace sufficient for pick-and-place operations and object manipulation tasks relevant to educational demonstrations.
Recent research explores ESP32 based manipulator control for educational applications, demonstrating WebSocket and Bluetooth control interfaces. These implementations validate microcontroller based servo control for multi joint arms, with studies reporting successful operation of 4-7 DOF systems using distributed control architectures. The integration of real-time feedback displays enhances user experience and facilitates debugging during development, representing best practices in embedded robotics design.
E. Research Gap and Contribution
While existing research demonstrates individual components mobile platforms with ESP32 control, robotic arms with microcontroller actuation, and wireless video streaming systems comprehensive integration of these capabilities within unified, cost-effective platforms remains limited. Most documented systems implement either mobility or manipulation, but not both with independent control architectures optimised for concurrent operation.
This work advances the state of art through several distinct contributions. First, the implementation of true distributed processing across heterogeneous microcontroller platforms (ESP32-CAM and Arduino Nano) demonstrates practical task allocation strategies maximising individual platform strengths. Second, the integration of multiple wireless protocols (WiFi for video, Bluetooth for control) within resource constrained hardware validates concurrent communication feasibility. Third, the modular power architecture with solar charging capability addresses deployment sustainability considerations often overlooked in research prototypes. Finally, comprehensive experimental validation across multiple performance dimensions provides quantitative assessment facilitating comparison with alternative approaches and informing future development efforts.

III. SYSTEM ARCHITECTURE AND DESIGN

A. Hardware Architecture Overview
The ZETABOT hardware architecture employs a distributed processing paradigm partitioning computational responsibilities across two specialised microcontroller units. The ESP32-CAM module serves as the primary system controller, managing wireless communications (Bluetooth and WiFi), motor driver coordination for the mobile platform, and video acquisition/streaming. The Arduino Nano operates as a dedicated manipulator controller, executing real-time servo positioning calculations and managing the LCD user interface. This architectural decision addresses the computational limitations of individual microcontrollers while maintaining system simplicity and cost effectiveness.
Inter controller communication utilises asynchronous serial protocol at 9600 baud, transmitting encoded command integers representing specific manipulator actions. This lightweight communication scheme minimises latency and processing overhead. The mobile platform employs tank style differential drive configuration with L298N dual H-bridge motor drivers, enabling omnidirectional mobility including forward/reverse translation and in place rotation.
B. Microcontroller Selection and Specifications
1) ESP32-CAM Module: The ESP32-CAM represents a critical component selection enabling advanced functionality within budget constraints. The ESP32-CAM module is based on the ESP32 dual-core Tensilica LX6 processor operating at up to 240 MHz, and integrates an OV2640 2-megapixel camera sensor, 520 KB of SRAM, and dual mode wireless connectivity (802.11 b/g/n Wi-Fi and Bluetooth). The dual-core architecture proves essential for concurrent execution of video encoding and wireless transmission tasks without compromising control responsiveness.
Key technical specifications include 4MB flash memory supporting firmware storage and temporary video buffering, multiple GPIO pins (though limited compared to standard ESP32 modules due to camera interface requirements), and onboard antenna for wireless communication. The module’s integrated voltage regulator accepts 5V input, simplifying power distribution design. Video streaming capability achieving 15-20 fps at VGA resolution (640×480) through HTTP server implementation represents significant functionality at approximately $10 component cost.


Fig. 1: Layout of ESP32-CAM module

2) Arduino Nano: The Arduino Nano, based on the ATmega328P microcontroller (16MHz, 32KB flash, 2KB SRAM), serves as the dedicated manipulator control unit. Its selection addresses specific advantages for servo control applications: hardware PWM capabilities on multiple pins enabling simultaneous servo actuation, extensive library support for servo control abstraction, and compact form factor (18×45mm) facilitating integration into the manipulator assembly. The Nano’s 19 digital I/O pins provide sufficient connectivity for six servo motors, I2C LCD interface, and serial communication with the ESP32-CAM. Power consumption characteristics (19mA active current) enable extended operation from the 7.4V lithium battery pack dedicated to the manipulator subsystem.


Fig. 2: Layout of Arduino Nano

C. Six-Degree-of-Freedom Manipulator Design

The robotic arm adopts a six-degree-of-freedom (6-DOF) anthropomorphic configuration consisting of base rotation (waist), shoulder articulation, elbow flexion, wrist pitch, wrist roll, and gripper actuation. This kinematic structure enables operation within a hemispherical workspace while maintaining computationally efficient inverse kinematics suitable for microcontroller-based implementation.
Each joint is actuated using an MG996R servo motor, which operates using pulse width modulation (PWM) control signals. The MG996R provides high torque output and reliable angular positioning, making it suitable for robotic manipulation tasks requiring stable load handling and repeatable motion.
The structural components are fabricated from laser cut acrylic panels to achieve a balance between mechanical rigidity and low overall weight. The arm provides an approximate base-to-gripper reach of 30 cm and supports payloads up to 100 g, which is sufficient for demonstration and light-duty manipulation applications.
The control system employs incremental joint positioning rather than absolute Cartesian coordinate targeting, thereby simplifying software complexity while maintaining adequate operational precision. Each servo is driven in discrete angular steps, and real-time system status is displayed via an LCD interface to provide user feedback and operational verification.
D. Tank Tracked Mobile Platform Configuration

The mobile base employs tracked drive configuration with independent left and right motors enabling differential steering. This design provides superior traction on irregular surfaces compared to wheeled alternatives, critical for field deployment scenarios. Two geared DC motors (12V, 150 RPM, 3 kg-cm torque) drive the tracks through 3D printed sprocket assemblies. The L298N H-bridge motor driver manages bidirectional control and enables PWM speed regulation, though the current implementation operates at fixed speed due to adequate performance for demonstration purposes. Platform dimensions of 175 mm × 180 mm × 85 mm (L × W × H, arm excluded), provide stable base for manipulator mounting while maintaining manoeuvrability in constrained environments. Total system weight of approximately 1.5kg enables operation duration exceeding 2 hours on battery capacity described subsequently.

E. Modular Power Management Architecture

The power architecture implements separate battery systems for mobility and manipulation subsystems, addressing distinct voltage and current requirements while simplifying fault isolation. The mobile platform operates from three series connected 18650 lithium ion cells providing 11.1V nominal voltage with 2500mAh capacity. An XL6019 DC-DC boost converter steps this voltage to 12V for motor driver operation, compensating for battery discharge characteristics. The manipulator subsystem utilises two 18650 cells (7.4V, 2500mAh) directly powering servos, with onboard 5V regulation for Arduino Nano and LCD display.

A 18650 3S charge management module enables simultaneous charging of the mobility battery pack while the manipulator pack charges independently. Integration of 5.5V, 70mA solar panels provides trickle charging capability extending deployment duration in outdoor scenarios, though primary recharging occurs through standard USB power adapters. This modular approach enables battery replacement without system shutdown and facilitates future capacity expansion. Measured power consumption averages 2.1A for the mobile platform during continuous operation and 0.8A for the manipulator during active manipulation, yielding operational duration of approximately 2.5 hours under typical duty cycles.


Fig. 3: Block diagram of the ZETABOT system architecture showing Bluetooth based command flow from the mobile application to the ESP32-CAM, distributed control with the Arduino Nano, and actuation through motor driver, LCD, and servo subsystems.


Fig. 4: Pictorial wiring diagram of the ZETABOT system showing physical interconnections between ESP32-CAM, Arduino Nano, motor driver, servo motors, LCD module, and power supply components.


Fig. 5: Electrical schematic of the ZETABOT control system illustrating signal routing, power distribution, and peripheral interfacing.

F. Physical Dimensions and Mechanical Specifications
The physical dimensions of the ZETABOT platform are summarised as follows:
- Arm height: 460 mm
- Tank base height: 85 mm
- Tank base length: 175 mm
- Tank base width: 180 mm
These dimensions provide a compact footprint suitable for operation in confined indoor environments while maintaining sufficient manipulator reach for object handling and inspection tasks. The low profile tracked base contributes to platform stability during arm articulation and motion over uneven surfaces.

IV. METHODOLOGY AND SYSTEM IMPLEMENTATION
A. Development Workflow
This project followed a structured engineering development methodology consisting of requirement analysis, hardware selection, system modelling, circuit design, firmware implementation, mobile application development, integration testing, and experimental validation. Figure 6 illustrates the overall development workflow adopted for the ZETABOT platform.


Fig. 6: ZETABOT system development methodology workflow.

B. Hardware Assembly Procedure

The hardware assembly of the ZETABOT platform was carried out using a modular and subsystem oriented approach to ensure reliability, ease of debugging, and scalability. The complete system was divided into four principal subsystems:
(i) processing and communication unit, (ii) mobile platform and motor drive unit, (iii) robotic manipulator unit, and (iv) power management unit. Each subsystem was independently assembled and tested before full system integration.
1) ESP32-CAM Programming and Configuration Setup: The ESP32-CAM module was designated as the primary controller for wireless communication, motor control, and real-time video streaming. Initial configuration was performed using an external USB-to-TTL (FTDI) converter module due to the absence of a native USB interface on the ESP32-CAM board.
Electrical connections were established as follows:
- ESP32-CAM 5V → FTDI 5V

- ESP32-CAM GND → FTDI GND
- ESP32-CAM U0R (RX) → FTDI TX
- ESP32-CAM U0T (TX) → FTDI RX
- ESP32-CAM GPIO0 → GND (temporary, to enable flashing mode)

The Arduino IDE was configured with the Espressif ESP32 board support package via the official package index repository. The AI Thinker ESP32-CAM board profile was selected during compilation and upload. After successful firmware flashing, the GPIO0-GND connection was removed and the module rebooted into execution mode.
The ESP32-CAM was physically mounted on the upper chassis layer to minimise electromagnetic interference from the motor driver circuitry and to provide an unobstructed field of view for the OV2640 camera module.
2) Arduino Nano Installation and Peripheral Interface: The Arduino Nano was employed as a dedicated real-time controller for the robotic arm and liquid crystal display (LCD) subsystem. The board was soldered onto a perforated vero board to improve mechanical stability and vibration resistance. The following connections were established:
- Serial communication lines:

– Arduino RX → ESP32-CAM TX (via logic-level compatible interface)
– Arduino TX → ESP32-CAM RX
- Power supply:

– VIN → 7.4 V battery pack (regulated onboard)
– GND → system common ground

This separation of processing tasks allowed the ESP32-CAM to focus on communication and mobility control while the Arduino Nano handled deterministic servo timing and display operations, preventing resource contention during peak loads.

3) Motor Driver and Mobile Platform Integration: A dual H-bridge L298N motor driver module was used to control the tracked mobile base. Two 12 V geared DC motors were mounted symmetrically on the left and right sides of the tank chassis using metal brackets to ensure alignment and minimise mechanical backlash.
Motor wiring was configured as:
- Motor A → OUT1 and OUT2 terminals
- Motor B → OUT3 and OUT4 terminals

Control signals were mapped to ESP32-CAM GPIO pins:

- IN1, IN2 → Left motor direction control
- IN3, IN4 → Right motor direction control

The motor driver supply voltage (VMS) was connected directly to the 11.1 V battery pack via the boost converter output. Logic voltage (5 V) was derived from the onboard regulator.


Fig. 7: Schematic diagram for motor drive module


Fig. 8: Layout of L298N Module

Rubberised tank tracks were installed over the sprockets and tensioned to prevent slippage during acceleration and turning. Static and dynamic rotation tests were conducted to verify correct polarity and direction mapping before integration with the robotic arm.

4) Robotic Arm Mechanical Assembly and Servo Installation: The manipulator structure was assembled using laser cut acrylic components arranged in a serial kinematic chain comprising base rotation, shoulder, elbow, wrist pitch, wrist rotation, and gripper actuation joints.
Each joint was actuated using an MG996R high-torque servo motor secured with M2 bolts and nylon spacers to reduce vibration transfer. Servo horn alignment was calibrated manually to establish a neutral reference position (90°) before mechanical fastening.
Servo wiring was standardised as:
- Red → +5 V supply
- Brown/Black → Ground
- Yellow/Orange → PWM control signal

The servo power rail was isolated from the logic supply using a dedicated 7.4 V battery pack to prevent voltage sag during high-torque movements.
Mechanical load testing confirmed stable articulation under a payload of approximately 100 g at full arm extension.


Fig. 9: Schematic diagram for MG996R Servo Motor


Fig. 10: Layout of MG996R Servo Motor

5) I2C LCD Module Integration: A 16×2 I2C LCD module was installed on the frontal panel of the platform to provide system status and operator feedback.
Connections were implemented as:
- LCD VCC → Arduino 5 V
- LCD GND → Arduino GND
- LCD SDA → Arduino A4
- LCD SCL → Arduino A5
The I2C backpack reduced wiring complexity from 16 conductors to four, improving reliability and ease of maintenance. The LCD was secured using vibration damping adhesive mounts.


Fig. 11: Layout of 16×2 LCD with I2C Module

6) Power System Assembly: The power architecture employed dual battery packs:
- Mobility pack: Three 18650 Li-ion cells in series (11.1 V nominal)
- Manipulator pack: Two 18650 Li-ion cells in series (7.4 V nominal)
A 3S lithium battery protection and charging module provided over-charge, over-discharge, and short-circuit protection. An XL6019 DC-DC boost converter regulated voltage supplied to the motor driver under varying load conditions.
A master toggle switch was installed on the main supply line for emergency shutdown. Ground lines from all subsystems were tied to a common reference to prevent floating potentials and communication instability.

Optional 5.5 V solar panels were connected through a charge controller to enable trickle charging during outdoor deployment.


Fig. 12: Layout of 18650 15A 3S Charger Module

7) Subsystem Validation Prior to Full Integration: Before full system coupling, each subsystem underwent standalone testing:
- ESP32-CAM: Bluetooth discovery, WiFi connection, camera stream verification
- Arduino Nano: Servo sweep tests, LCD output validation
- Motor driver: Forward, reverse, and pivot rotation tests
- Power system: Voltage stability and current draw measurement
Only after successful validation were the subsystems mechanically and electrically integrated into the final ZETABOT platform.
C. Firmware Development Methodology
The ZETABOT platform employs a distributed firmware architecture in which the ESP32-CAM and Arduino Nano execute independent but coordinated control programs. This separation enables real-time motor and vision processing to be handled by the ESP32-CAM while deterministic servo control and user feedback display are managed by the Arduino Nano. The two controllers communicate through a lightweight asynchronous serial protocol, allowing reliable command exchange with minimal computational overhead.
1) ESP32-CAM Firmware Implementation: The ESP32-CAM firmware was developed using the Arduino framework and structured into four functional layers: Bluetooth communication handling, command parsing and dispatch, motor control via GPIO mapping, and WiFi based camera streaming using an embedded HTTP server.
a) Bluetooth Communication Using Bluetooth Serial Library: Wireless command reception is implemented using the built-in Bluetooth Serial library provided by the ESP32 SDK. This library enables the microcontroller to operate as a Bluetooth Classic Serial Port Profile (SPP) device, allowing direct pairing with Android smartphones without additional middleware or network configuration.
During system initialisation, the ESP32-CAM advertises itself using a unique device identifier (“ZETABOT”). Once paired, the microcontroller listens continuously on the Bluetooth serial buffer for incoming ASCII encoded control commands transmitted by the mobile application.

This approach provides:
- Low-latency communication suitable for human-in-theloop control
- Minimal memory footprint
- High compatibility with Android devices
- Simple integration with Arduino based firmware environments
b) Command Parser Design: Incoming Bluetooth data is processed using a character buffer accumulation strategy. Characters are appended to a temporary command string until a termination symbol (“#”) is detected. This delimiter indicates completion of a command packet and triggers parsing logic. The parser then compares the decoded command against predefined instruction tokens representing:
- Mobile platform motion commands (forward, reverse, left, right, stop)
- Lighting control
- Robotic arm joint movement commands
Each recognised command is translated into either direct GPIO actuation (for motors and lighting) or encoded serial messages forwarded to the Arduino Nano for manipulator control.
This string based protocol simplifies debugging and ensures resilience against partial packet reception or transmission noise.
c) Motor GPIO Mapping Strategy: The ESP32-CAM controls the L298N dual H-bridge motor driver using four digital GPIO outputs. Each output corresponds to one direction control pin of the motor driver:
- IN1, IN2 → Left track motor direction
- IN3, IN4 → Right track motor direction
Logical combinations of HIGH and LOW signals implement the following motion primitives:

TABLE I: Motor GPIO Mapping for Motion Control

Motion Mode | IN1 | IN2 | IN3 | IN4
Forward | 1 | 0 | 1 | 0
Reverse | 0 | 1 | 0 | 1
Rotate Left | 0 | 1 | 1 | 0
Rotate Right | 1 | 0 | 0 | 1
Stop | 0 | 0 | 0 | 0

This direct mapping minimises processing overhead and ensures rapid response to operator input.
d) HTTP Camera Server Implementation: Real-time video streaming is achieved using the official ESP32 CameraWebServer example provided within the ESP32 Arduino SDK. The firmware initialises the OV2640 camera module and configures an embedded HTTP server operating on port 80.
Key characteristics include:
- MJPEG stream format
- VGA resolution (640 × 480)
- Frame rate of 15-20 fps
- Dynamic IP allocation via DHCP

Upon startup, the assigned IP address is transmitted over the serial monitor for client access. Any device connected to the same WiFi network can access the live stream through a standard web browser or video client.
This implementation enables visual navigation and manipulation feedback without requiring additional hardware or cloud infrastructure.
2) Arduino Nano Firmware Implementation: The Arduino Nano firmware was developed to provide deterministic control of the robotic arm and real-time system feedback through the LCD module. The firmware architecture consists of four primary components: serial command interpretation, servo actuation, LCD initialisation and messaging, and safety boundary enforcement.
a) Serial Communication Protocol: The Arduino Nano communicates with the ESP32-CAM via UART at 9600 baud. Commands are transmitted as integer values representing discrete motion operations for individual joints.
This numeric protocol was selected to:
- Reduce transmission overhead
- Simplify parsing logic
- Improve reliability under noisy electrical conditions Upon reception of a valid command integer, the microcontroller triggers the corresponding servo motion routine and updates the LCD status display.
b) Servo Control Using Arduino Servo Library: The standard Servo.h library is used to generate PWM signals required for angular positioning of each joint actuator. Six servo objects are instantiated, corresponding to:
1) Base (waist)
2) Shoulder
3) Elbow
4) Wrist pitch
5) Wrist rotation
6) Gripper
Servo positions are stored in software variables to maintain state awareness and support incremental movement. Each command adjusts the servo position by a fixed angular step (typically 5-10 degrees) to allow smooth and controlled motion.
Mechanical safety limits are enforced in software to prevent commands exceeding the physical joint range.
c) LCD Initialisation and User Feedback: A 16×2 LCD module connected via I2C is initialised during startup using the LiquidCrystal I2C library. The display provides real-time system feedback including:
- System boot confirmation
- Bluetooth and WiFi connection status
- Active operation mode
- User identification message
LCD feedback improves operator confidence and simplifies debugging during development and field deployment.
d) Command Mapping Table: The Arduino firmware maintains a fixed mapping between received command integers and physical joint actions, as summarised below:

TABLE II: Command Code Mapping for Robotic Arm Control

Command Code | Joint | Action
31 / 32 | Base | Rotate right/left
33 / 34 | Shoulder | Up / Down
35 / 36 | Elbow | Up / Down
37 / 38 | Wrist pitch | Up / Down
39 / 40 | Wrist rotate | Right / Left
41 / 42 | Gripper | Open / Close

This abstraction decouples high-level user interaction from low-level actuation logic, enabling future extension without modifying the mobile application protocol.
The complete firmware source code is publicly available in the project GitHub repository for reproducibility and community development.
D. Android Application Development Using Kodular
The Android control application was developed using Kodular, a block based visual programming environment derived from MIT App Inventor. This approach enables rapid interface design and reliable Bluetooth integration without extensive native Android programming overhead.
1) User Interface Design: The application interface was designed to prioritise simplicity and operational clarity. The layout consists of:
- Directional control pad for mobile platform navigation
- Individual joint control buttons for robotic arm manipulation
- Bluetooth connection management controls
- System status indicators
Large touch targets and high contrast icons were employed to ensure usability under outdoor lighting conditions and on small screen devices.
2) Bluetooth SPP Communication: The application uses Bluetooth Classic Serial Port Profile (SPP) to communicate with the ESP32-CAM. Upon launch, the application scans for nearby devices, identifies the ZETABOT module, and establishes a persistent serial connection.
Connection status is continuously monitored, and automatic reconnection is attempted if communication is interrupted.
3) Command Encoding Strategy: Each button press generates a predefined ASCII command sequence terminated by the “#” delimiter. Commands are transmitted immediately without buffering to minimise control latency.
This stateless protocol ensures:
- Fast response
- Minimal processing requirements on the microcontroller
- Robust recovery after temporary connection loss
4) Testing Using Kodular Companion: During development, the Kodular Companion application was used to test interface logic in real time on physical Android devices. This enabled iterative debugging of:
- Button event handling
- Bluetooth pairing logic
- Command transmission reliability
- Interface layout scaling across different screen sizes

The final application package (APK) was exported and installed on multiple test devices to validate cross device compatibility.


Fig. 13: Zetabot App development interface


Fig. 14: Screenshot of the Zetabot App

E. System Integration and Testing Procedure
System integration followed a structured incremental methodology to minimise fault propagation and simplify troubleshooting.
1) Step-Wise Integration Process: The integration sequence proceeded as follows:
1) Standalone validation of ESP32-CAM Bluetooth and WiFi functionality
2) Standalone validation of Arduino Nano servo control and LCD output
3) Motor driver and mobile base integration with ESP32-CAM

4) Serial communication linkage between both microcontrollers
5) Power subsystem coupling
6) Mechanical assembly of full platform

Each stage was verified before proceeding to the next.
2) Unit Testing of Subsystems: Subsystem level testing included:
- Motor direction and braking verification
- Servo angular accuracy testing
- LCD message rendering
- Bluetooth command reliability
- Camera stream stability
- Battery voltage regulation under load

Faults were isolated and corrected at this stage to prevent cascading failures during full system operation.
3) End-to-End Functional Testing: After complete assembly, the system underwent end-to-end testing involving simultaneous:
- Mobile navigation
- Robotic arm manipulation
- Live video streaming
- LCD feedback monitoring

Latency, command accuracy, and system stability were measured during continuous operation cycles exceeding 30 minutes.
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

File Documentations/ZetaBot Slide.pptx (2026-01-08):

## DESIGN AND CONSTRUCTION OF A MOBILE CONTROL ROBOT ARM ON A ROBOTIC WHEEL


OKE IYANUOLUWA E.
17BD005101

SUPERVISOR
DR. P.K OLULOPE

## INTRODUCTION

- Robot, any automatically operated machine that replaces human effort, though it may not resemble human beings in appearance or perform functions in a humanlike manner.
- Three Laws of Robotics:
- A robot may not injure a human being, or, through inaction, allow a human being to come to harm.
- A robot must obey the orders given it by human beings except where such orders would conflict with the First Law.
- A robot must protect its own existence as long as such protection does not conflict with the First or Second Law.
- Hydroponic farming is a method of growing plants in water, not in soil.
Reasons for Hydroponic Farming:
- LESS LAND USAGE
- YOU CAN GROW PRODUCE YEAR-ROUND
- LESS WATER USAGE
- LOWER LABOUR REQUIREMENTS


## STATEMENT OF PROBLEM


Robotic advancements will reduce the number of high-end precision tasks and will benefit a variety of industries, including agriculture, military, and health care. As a result, robots will be used as workplace assistants with a degree of balance between genuine requirements and greed. Many jobs that are beyond human capability can be accomplished with the aid of robotics, which will be quite beneficial in its functioning.

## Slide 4

AIM & OBJECTIVES


AIM:
To develop a low-cost research robot used in any area of field.
OBJECTIVES:
- To design an inexpensive system that is user-friendly and easy to use.
- To construct a mobile app control robot for research purpose.
- To develop an internet base control system that enables transfer and receiving data through the internet.
- To interface the system with an internet android application enabling cloud data communication.

## Methodology


## Methodology


## SYSTEM DESIGN


## PICTORIAL CIRCUIT DIAGRAM

Diagram, schematic Description generated with very high confidence

## CIRCUIT DIAGRAM DESIGN

Diagram, schematic Description generated with very high confidence

## Meet ZetaBot


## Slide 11

Tablet APP
(Tank Section)


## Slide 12

Tablet APP
(Arm Section)


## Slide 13


CONCLUSION
- I successfully designed and implemented the proposed low-cost robot. The mobile app is user friendly and self-explanatory, once the mobile is connected to the robot is shows connected and the robot displaying a welcome message indicating the robot is still booting. With this project being designed and implemented, a user-friendly, scalable, open-source and low-cost agrotechnology is believed to have been achieved.
- Although, the project was initially planned to be operated over the Internet instead of Bluetooth Connection, this was due to lack of strong internet and availability of materials need for the seamless transmission.

## Thank You !

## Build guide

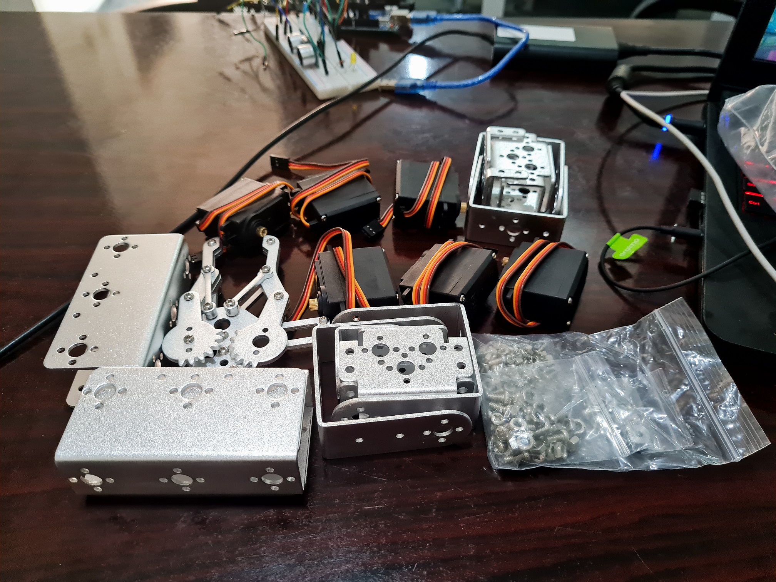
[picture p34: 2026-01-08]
Building/20210712_103140_01_saved.jpg

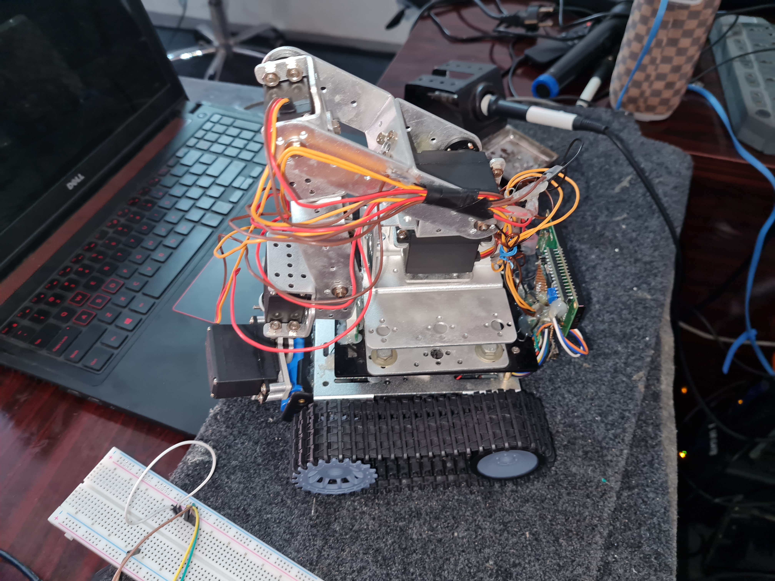
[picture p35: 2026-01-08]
Building/20210807_154052.jpg

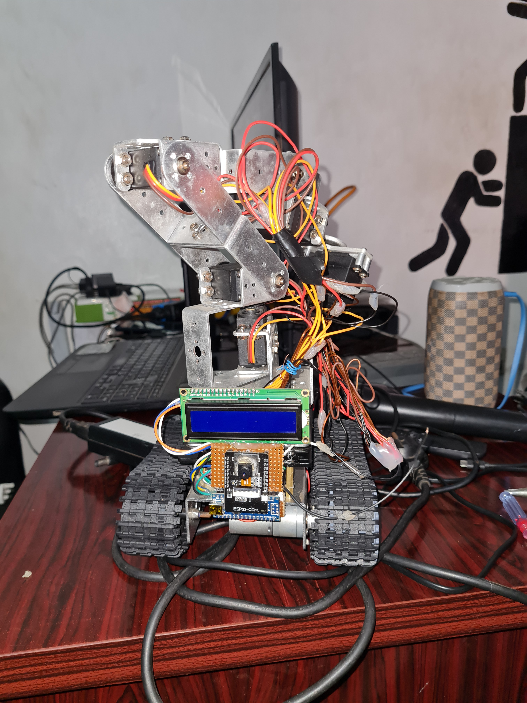
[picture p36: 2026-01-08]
Building/20210807_152212.jpg

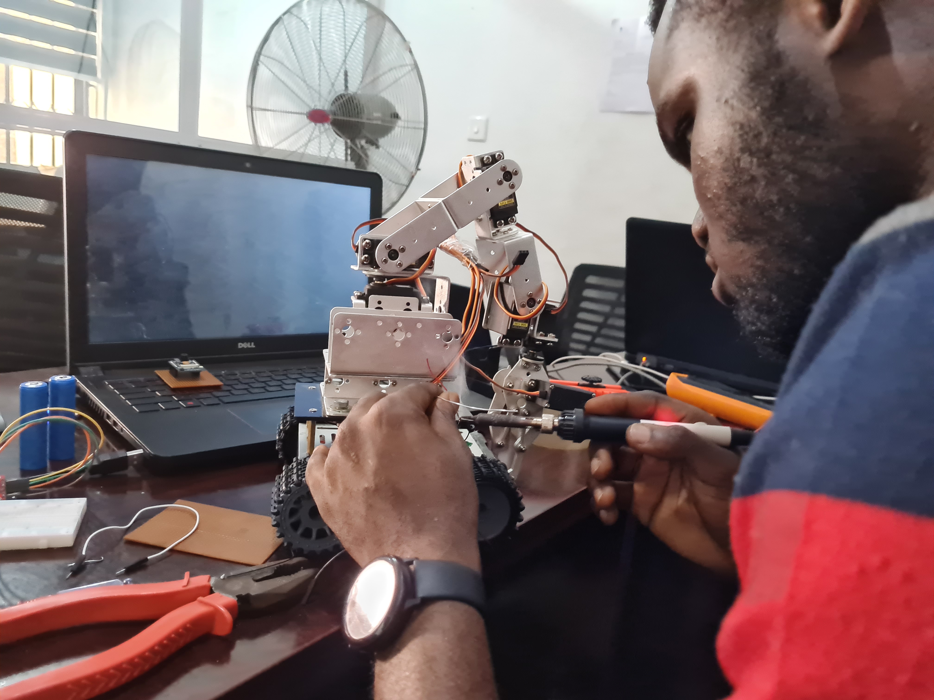
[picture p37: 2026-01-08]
Building/20210728_153559.jpg

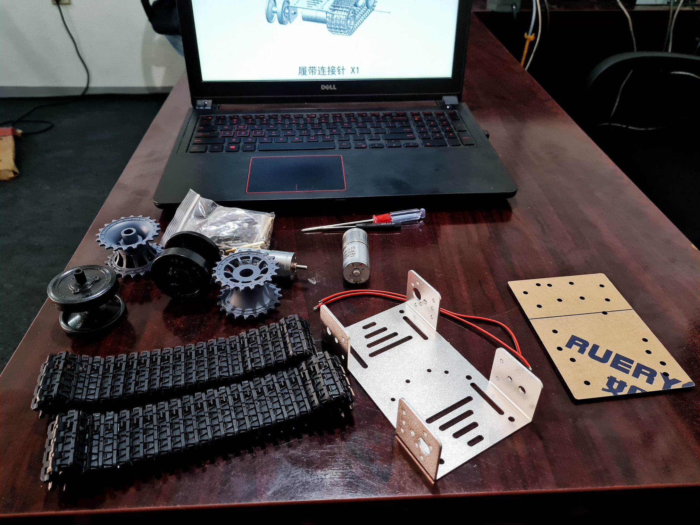
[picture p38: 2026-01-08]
Building/20210621_135055_01_saved.jpg

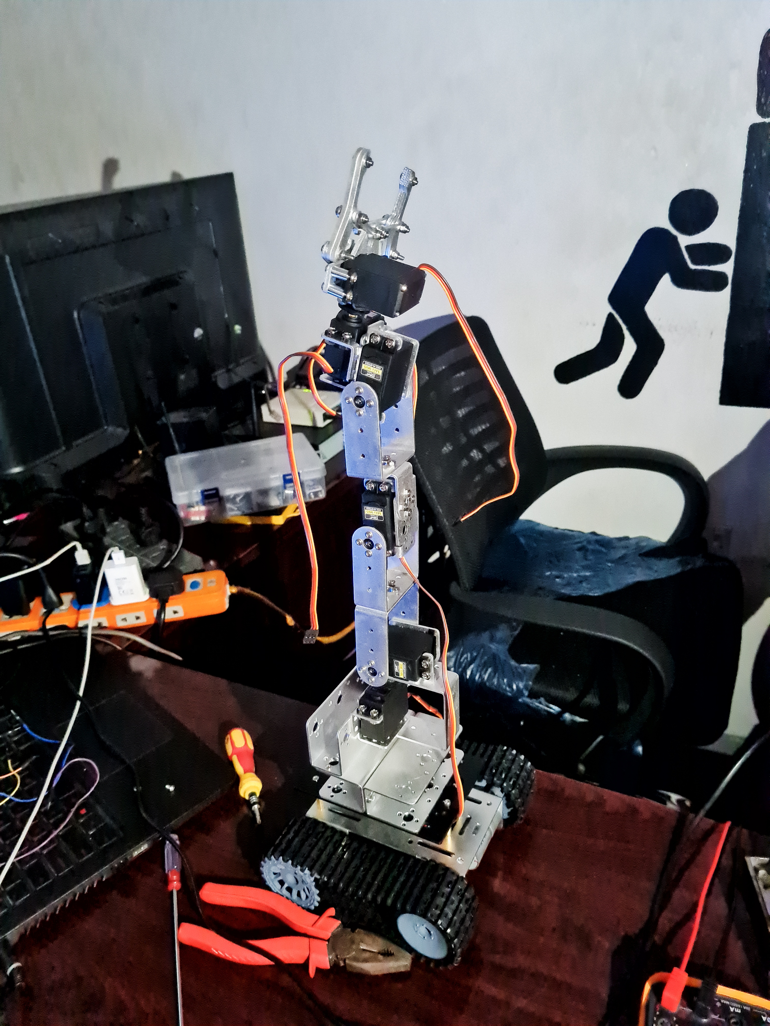
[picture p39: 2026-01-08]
Building/20210712_181948_01_saved.jpg

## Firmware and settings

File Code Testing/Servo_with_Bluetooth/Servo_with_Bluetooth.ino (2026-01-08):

#include <SoftwareSerial.h>
#include <Servo.h>
Servo servo01;
Servo servo02;
Servo servo03;
Servo servo04;
Servo servo05;
Servo servo06;
SoftwareSerial Bluetooth(3, 4); // Arduino(RX, TX) - HC-05 Bluetooth (TX, RX)
int servo1Pos, servo2Pos, servo3Pos, servo4Pos, servo5Pos, servo6Pos; // current position
int servo1PPos, servo2PPos, servo3PPos, servo4PPos, servo5PPos, servo6PPos; // previous position
int servo01SP[50], servo02SP[50], servo03SP[50], servo04SP[50], servo05SP[50], servo06SP[50]; // for storing positions/steps
int speedDelay = 20;
int index = 0;
String dataIn = "";
void setup() {
  servo01.attach(5);
  servo02.attach(6);
  servo03.attach(7);
  servo04.attach(8);
  servo05.attach(9);
  servo06.attach(10);
  Bluetooth.begin(38400); // Default baud rate of the Bluetooth module
  Bluetooth.setTimeout(1);
  delay(20);
  // Robot arm initial position
  servo1PPos = 90;
  servo01.write(servo1PPos);
  servo2PPos = 150;
  servo02.write(servo2PPos);
  servo3PPos = 35;
  servo03.write(servo3PPos);
  servo4PPos = 140;
  servo04.write(servo4PPos);
  servo5PPos = 85;
  servo05.write(servo5PPos);
  servo6PPos = 80;
  servo06.write(servo6PPos);
}
void loop() {
  // Check for incoming data
  if (Bluetooth.available() > 0) {
    dataIn = Bluetooth.readString();  // Read the data as string
    
    // If "Waist" slider has changed value - Move Servo 1 to position
    if (dataIn.startsWith("s1")) {
      String dataInS = dataIn.substring(2, dataIn.length()); // Extract only the number. E.g. from "s1120" to "120"
      servo1Pos = dataInS.toInt();  // Convert the string into integer
      // We use for loops so we can control the speed of the servo
      // If previous position is bigger then current position
      if (servo1PPos > servo1Pos) {
        for ( int j = servo1PPos; j >= servo1Pos; j--) {   // Run servo down
          servo01.write(j);
          delay(20);    // defines the speed at which the servo rotates
        }
      }
      // If previous position is smaller then current position
      if (servo1PPos < servo1Pos) {
        for ( int j = servo1PPos; j <= servo1Pos; j++) {   // Run servo up
          servo01.write(j);
          delay(20);
        }
      }
      servo1PPos = servo1Pos;   // set current position as previous position
    }
    
    // Move Servo 2
    if (dataIn.startsWith("s2")) {
      String dataInS = dataIn.substring(2, dataIn.length());
      servo2Pos = dataInS.toInt();
      if (servo2PPos > servo2Pos) {
        for ( int j = servo2PPos; j >= servo2Pos; j--) {
          servo02.write(j);
          delay(50);
        }
      }
      if (servo2PPos < servo2Pos) {
        for ( int j = servo2PPos; j <= servo2Pos; j++) {
          servo02.write(j);
          delay(50);
        }
      }
      servo2PPos = servo2Pos;
    }
    // Move Servo 3
    if (dataIn.startsWith("s3")) {
      String dataInS = dataIn.substring(2, dataIn.length());
      servo3Pos = dataInS.toInt();
      if (servo3PPos > servo3Pos) {
        for ( int j = servo3PPos; j >= servo3Pos; j--) {
          servo03.write(j);
          delay(30);
        }
      }
      if (servo3PPos < servo3Pos) {
        for ( int j = servo3PPos; j <= servo3Pos; j++) {
          servo03.write(j);
          delay(30);
        }
      }
      servo3PPos = servo3Pos;
    }
    // Move Servo 4
    if (dataIn.startsWith("s4")) {
      String dataInS = dataIn.substring(2, dataIn.length());
      servo4Pos = dataInS.toInt();
      if (servo4PPos > servo4Pos) {
        for ( int j = servo4PPos; j >= servo4Pos; j--) {
          servo04.write(j);
          delay(30);
        }
      }
      if (servo4PPos < servo4Pos) {
        for ( int j = servo4PPos; j <= servo4Pos; j++) {
          servo04.write(j);
          delay(30);
        }
      }
      servo4PPos = servo4Pos;
    }
    // Move Servo 5
    if (dataIn.startsWith("s5")) {
      String dataInS = dataIn.substring(2, dataIn.length());
      servo5Pos = dataInS.toInt();
      if (servo5PPos > servo5Pos) {
        for ( int j = servo5PPos; j >= servo5Pos; j--) {
          servo05.write(j);
          delay(30);
        }
      }
      if (servo5PPos < servo5Pos) {
        for ( int j = servo5PPos; j <= servo5Pos; j++) {
          servo05.write(j);
          delay(30);
        }
      }
      servo5PPos = servo5Pos;
    }
    // Move Servo 6
    if (dataIn.startsWith("s6")) {
      String dataInS = dataIn.substring(2, dataIn.length());
      servo6Pos = dataInS.toInt();
      if (servo6PPos > servo6Pos) {
        for ( int j = servo6PPos; j >= servo6Pos; j--) {
          servo06.write(j);
          delay(30);
        }
      }
      if (servo6PPos < servo6Pos) {
        for ( int j = servo6PPos; j <= servo6Pos; j++) {
          servo06.write(j);
          delay(30);
        }
      }
      servo6PPos = servo6Pos; 
    }
    // If button "SAVE" is pressed
    if (dataIn.startsWith("SAVE")) {
      servo01SP[index] = servo1PPos;  // save position into the array
      servo02SP[index] = servo2PPos;
      servo03SP[index] = servo3PPos;
      servo04SP[index] = servo4PPos;
      servo05SP[index] = servo5PPos;
      servo06SP[index] = servo6PPos;
      index++;                        // Increase the array index
    }
    // If button "RUN" is pressed
    if (dataIn.startsWith("RUN")) {
      runservo();  // Automatic mode - run the saved steps 
    }
    // If button "RESET" is pressed
    if ( dataIn == "RESET") {
      memset(servo01SP, 0, sizeof(servo01SP)); // Clear the array data to 0
      memset(servo02SP, 0, sizeof(servo02SP));
      memset(servo03SP, 0, sizeof(servo03SP));
      memset(servo04SP, 0, sizeof(servo04SP));
      memset(servo05SP, 0, sizeof(servo05SP));
      memset(servo06SP, 0, sizeof(servo06SP));
      index = 0;  // Index to 0
    }
  }
}
// Automatic mode custom function - run the saved steps
void runservo() {
  while (dataIn != "RESET") {   // Run the steps over and over again until "RESET" button is pressed
    for (int i = 0; i <= index - 2; i++) {  // Run through all steps(index)
      if (Bluetooth.available() > 0) {      // Check for incomding data
        dataIn = Bluetooth.readString();
        if ( dataIn == "PAUSE") {           // If button "PAUSE" is pressed
          while (dataIn != "RUN") {         // Wait until "RUN" is pressed again
            if (Bluetooth.available() > 0) {
              dataIn = Bluetooth.readString();
              if ( dataIn == "RESET") {     
                break;
              }
            }
          }
        }
        // If speed slider is changed
        if (dataIn.startsWith("ss")) {
          String dataInS = dataIn.substring(2, dataIn.length());
          speedDelay = dataInS.toInt(); // Change servo speed (delay time)
        }
      }
      // Servo 1
      if (servo01SP[i] == servo01SP[i + 1]) {
      }
      if (servo01SP[i] > servo01SP[i + 1]) {
        for ( int j = servo01SP[i]; j >= servo01SP[i + 1]; j--) {
          servo01.write(j);
          delay(speedDelay);
        }
      }
      if (servo01SP[i] < servo01SP[i + 1]) {
        for ( int j = servo01SP[i]; j <= servo01SP[i + 1]; j++) {
          servo01.write(j);
          delay(speedDelay);
        }
      }
      // Servo 2
      if (servo02SP[i] == servo02SP[i + 1]) {
      }
      if (servo02SP[i] > servo02SP[i + 1]) {
        for ( int j = servo02SP[i]; j >= servo02SP[i + 1]; j--) {
          servo02.write(j);
          delay(speedDelay);
        }
      }
      if (servo02SP[i] < servo02SP[i + 1]) {
        for ( int j = servo02SP[i]; j <= servo02SP[i + 1]; j++) {
          servo02.write(j);
          delay(speedDelay);
        }
      }
      // Servo 3
      if (servo03SP[i] == servo03SP[i + 1]) {
      }
      if (servo03SP[i] > servo03SP[i + 1]) {
        for ( int j = servo03SP[i]; j >= servo03SP[i + 1]; j--) {
          servo03.write(j);
          delay(speedDelay);
        }
      }
      if (servo03SP[i] < servo03SP[i + 1]) {
        for ( int j = servo03SP[i]; j <= servo03SP[i + 1]; j++) {
          servo03.write(j);
          delay(speedDelay);
        }
      }
      // Servo 4
      if (servo04SP[i] == servo04SP[i + 1]) {
      }
      if (servo04SP[i] > servo04SP[i + 1]) {
        for ( int j = servo04SP[i]; j >= servo04SP[i + 1]; j--) {
          servo04.write(j);
          delay(speedDelay);
        }
      }
      if (servo04SP[i] < servo04SP[i + 1]) {
        for ( int j = servo04SP[i]; j <= servo04SP[i + 1]; j++) {
          servo04.write(j);
          delay(speedDelay);
        }
      }
      // Servo 5
      if (servo05SP[i] == servo05SP[i + 1]) {
      }
      if (servo05SP[i] > servo05SP[i + 1]) {
        for ( int j = servo05SP[i]; j >= servo05SP[i + 1]; j--) {
          servo05.write(j);
          delay(speedDelay);
        }
      }
      if (servo05SP[i] < servo05SP[i + 1]) {
        for ( int j = servo05SP[i]; j <= servo05SP[i + 1]; j++) {
          servo05.write(j);
          delay(speedDelay);
        }
      }
      // Servo 6
      if (servo06SP[i] == servo06SP[i + 1]) {
      }
      if (servo06SP[i] > servo06SP[i + 1]) {
        for ( int j = servo06SP[i]; j >= servo06SP[i + 1]; j--) {
          servo06.write(j);
          delay(speedDelay);
        }
      }
      if (servo06SP[i] < servo06SP[i + 1]) {
        for ( int j = servo06SP[i]; j <= servo06SP[i + 1]; j++) {
          servo06.write(j);
          delay(speedDelay);
        }
      }
    }
  }
}
